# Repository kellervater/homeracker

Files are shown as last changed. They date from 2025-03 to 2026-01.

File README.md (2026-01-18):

[📚 What's it for?](#-use-cases) | [⚙️ How does it work?](#-features) | [🌐 Free & OpenSource](#-open-specs) | [🤝 Contributing](CONTRIBUTING.md)

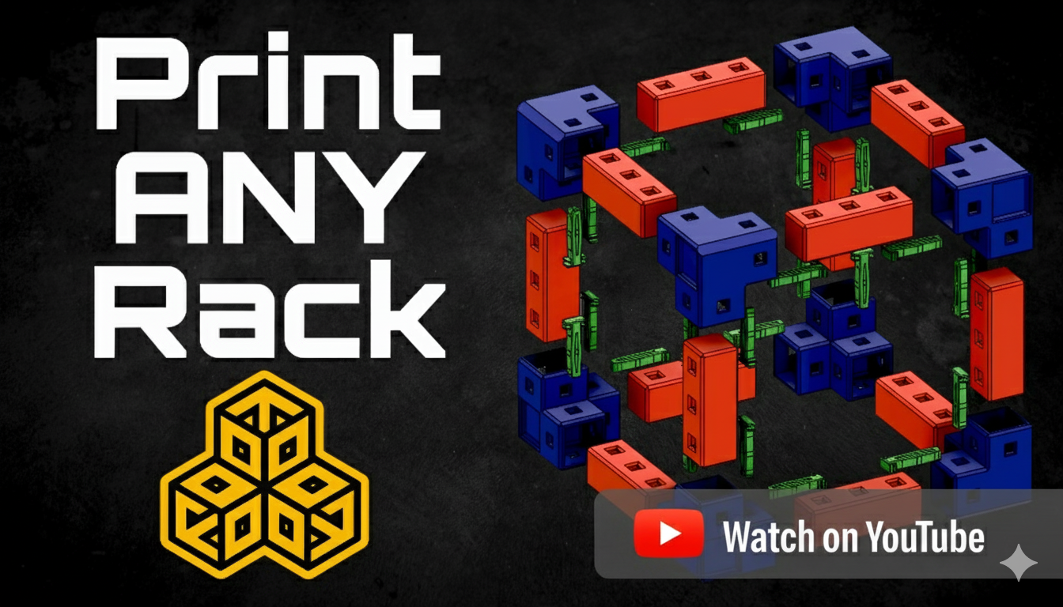
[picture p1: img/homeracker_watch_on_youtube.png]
What is HomeRacker - YouTube video (https://youtu.be/g8k6X_axYug)


HomeRacker is a fully modular 3D-printable rack-building system for virtually any “racking needs” (server rack, shoe rack, bookshelf, you name it).

You can find all parametric and non-parametric models, as well as the `.f3d` files (like the `HomeRacker - Core`), on [Makerworld](https://makerworld.com/en/@kellerlab).

The parametric models are available in the [HomeRacker GitHub Repository](https://github.com/kellerlabs/homeracker/tree/main/models).

> 💡 **Note**
> The basic HomeRacker system is also referred to as `HomeRacker - Core`. Free for everyone to use, remix, and reshare.

# 📑 Table of Contents
- [🔧 Use Cases](#-use-cases)
- [✨ Features](#-features)
  - [⚙️ How it works](#%EF%B8%8F-how-it-works)
    - [🛠️ Assembly Basics](#%EF%B8%8F-assembly-basics)
    - [💡 Assembly Tips](#-assembly-tips)
    - [🖨️ Printing Tips](#%EF%B8%8F-printing-tips)
- [📐 Tech Specs](#-tech-specs)
  - [🧱 Supports](#-supports)
  - [🔗 Connectors](#-connectors)
  - [📏 Lock Pins](#-lock-pins)
  - [🌍 Open Specs](#-open-specs)
- [💬 Community](#-community)
- [❓ Why the name?](#-why-the-name)
- [📜 Licensing](#-licensing)
- [🤝 Contributing](CONTRIBUTING.md)
- [🛠️ Developer Tools](#%EF%B8%8F-developer-tools)
- [🚀 Releases](#-releases)
- [🧪 Tests](#-tests)
  - [⚠️ Disclaimer](#%EF%B8%8F-disclaimer)
  - [🔬 How I tested](#-how-i-tested)

# 🔧 Use Cases
I created HomeRacker because I was dissatisfied with the existing solutions available online.
Many designs were too specific—accommodating only certain devices owned by their creators. Others supported only the 10" standard, with no flexibility for deviations, often requiring additional adapters.

As I began my homelab journey in April 2025, I wanted a modular solution that could adapt and grow with my evolving needs. This would eliminate the need to purchase larger racks or completely change concepts when the original design no longer met my requirements.

xkcd: The General Problem

As it is my nature to overengineer everything, I came up with a more generic solution to serve ANY racking need. Be it a small rack for a few Raspberry Pis, a 10" standard rack for homelabs, or even a 19" standard rack (still working on that though). You can even create bookshelves, shoe racks—or combine all of the above into an abomination of a rack.

To give you an idea of how this may look (10" rack, half-constructed Pi mini-rack, bookshelf):

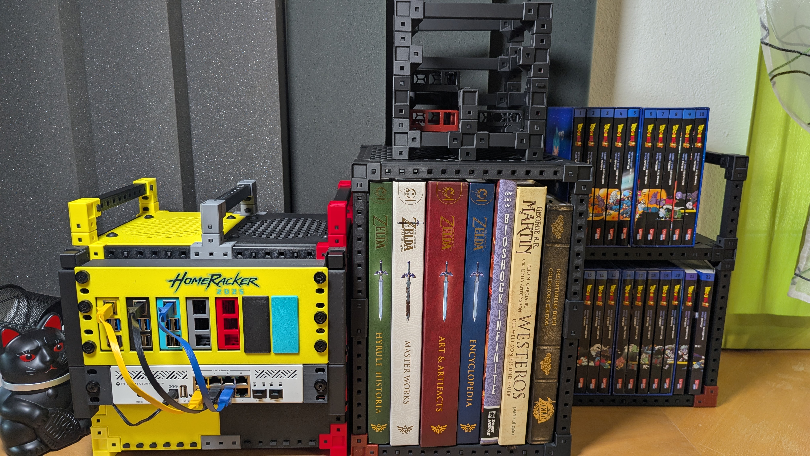
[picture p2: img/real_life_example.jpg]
Real Life Example


Aside from the basic [building blocks](#-tech-specs), the rack above also contains the following parts:

* **10" Rack**
  * [HomeRacker - 10" Rackmount Kit](https://makerworld.com/en/models/1353730-modular-10-server-rack#profileId-1396904) for standard-height units
  * [Raspi 5 Mount Kit](https://makerworld.com/en/models/1324096-pi-5-snapcase-for-homeracker#profileId-1360937):
    * Vertical Mount Adapter for HomeRacker
    * Front panel for 10" racks
  * Rackmount ears for the switch. These are fully customizable rackmount ears I created as an [OpenSCAD file](https://github.com/kellerlabs/homeracker/blob/main/models/rackmount_ears/rackmount_ears.scad). You can customize it directly [here](https://makerworld.com/en/models/1259227-fully-customizable-rackmount-ears#profileId-1283271).
  * [HomeRacker Airflow Kit](https://makerworld.com/en/models/1353730-modular-10-server-rack#profileId-1396904) (currently part of the 10" rack model), which consists of:
    * Front/back panels
    * Side panels
    * Bottom/top panels with air intake/exhaust grids and bores for standard fans (80/92/120mm)

* **Shelf** (Build any shelf configuration you like.)

# ✨ Features

The `HomeRacker - Core` features:

* **Fully modular** – Thanks to the support-connector system, you can scale in any direction. The only limits are material strength—and how much money, space, and time you have.
* **3D-printable** – The entire core system is printable, and no tools are required for assembly.
* **No supports needed** – Not a single part of the core system needs printed supports.
* **OpenSource** – Build your own adapters and use the system in personal or commercial projects (see [🌍 Open Specs](#-open-specs) and [📜 Licensing](#-licensing) for details).

## ⚙️ How it works
> **tl;dr** Think of a rack shape you want to build, download the model (insert link), print it, assemble it, and add your own mounts/adapters/whatever-you-like.

I might post a YouTube video here to show how it works.

### 🛠️ Assembly Basics

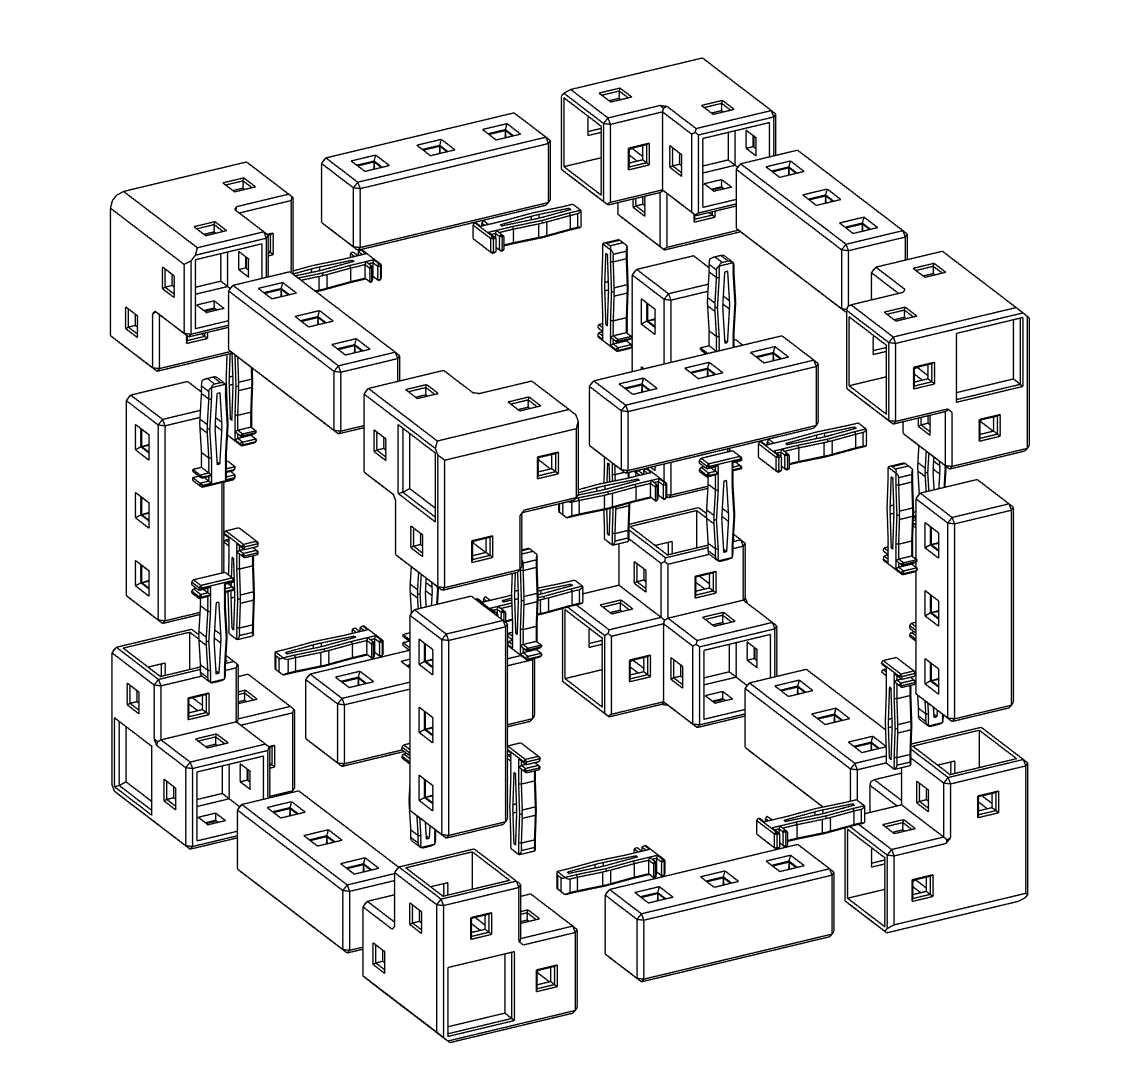
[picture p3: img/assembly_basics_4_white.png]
Assembly Basics 4 White


Assembly is straightforward and requires no tools:

1. **Prepare the components**: Download the HomeRacker - Core (❗Todo: insert link), and print all required parts. Clean off any debris.
2. **Connect supports and connectors**: Attach connectors to supports based on your desired configuration.
3. **Secure with Lock Pins**: Use Lock Pins to lock parts in place. They can be inserted horizontally or vertically thanks to their square profile.
4. **Add features**: Attach panels, shelves, and other accessories as needed.

### 💡 Assembly Tips

> 💡 **Pro Tip**: I created a sample 10" Cyberpunk-themed 3D model on MakerWorld (❗Todo: insert link) for inspiration.

1. Plan ahead! Otherwise, you'll end up with an army of unused parts like me:

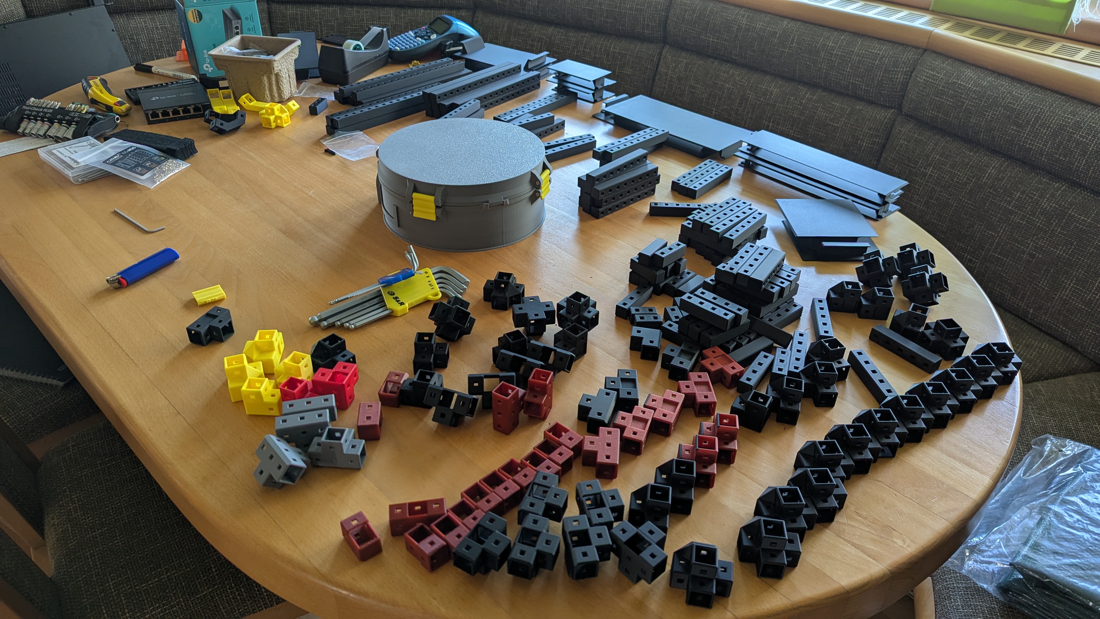
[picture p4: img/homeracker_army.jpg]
Army of Parts
   

   Make a parts list:
   * How many supports of what lengths (in `base units`)?
   * How many connectors of each type (pull-throughs, feet, regular)?
   * Print a ton of Lock Pins. You’ll need more than you might think. The model (❗Todo: insert link) on Makerworld should include a 100-pin plate and a [Gridfinity](https://gridfinity.xyz/) box for storage.

2. Build layer by layer: Start with the base frame, add vertical supports, then stack intermediate/top frames.
3. Make sure Lock Pins are fully inserted—gentle force might be needed.

### 🖨️ Printing Tips

1. If bed adhesion is sketchy: Add a brim to the supports. The small contact surface on connectors can cause print failures.
2. Prevent warping: Keep the print bed clean and oil-free. Even a fingerprint can cause issues.
3. When printing new filament: Make sure to calibrate the material flow!
> 💡 **Pro Tip**: If you need to disassemble and the pin is stuck, push it from the other side with another pin to release it.

## 📐 Tech Specs

> 💡 **Note** - For actual dimensions, check out the original Fusion `.f3d` files on Makerworld. All designs are fully parameterized for easy scaling.

The system is based on 4 core measurements:

1. **15mm** – The `base_unit`. Each support has 15mm x/y dimensions, with z being a multiple of 15mm.
2. **4mm** – Side length of Lock Pins and matching holes.
3. **2mm** – Wall thickness of connectors.
4. **0.2mm** – Tolerance added to connector interiors for print/material variances.

> These values (except tolerance) are arbitrary—just made sense during design.

### 🧱 Supports

Supports are the structural spine of HomeRacker.

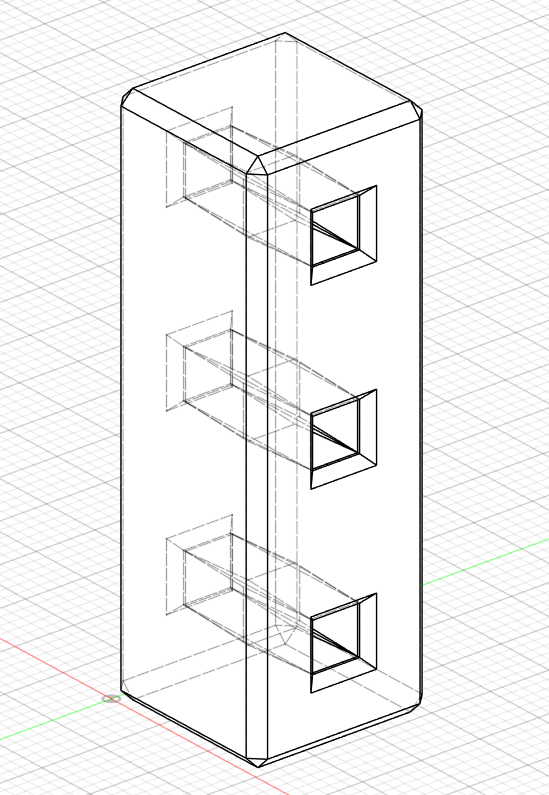
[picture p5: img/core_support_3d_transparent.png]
Core Support 3D Transparent


Height is a multiple of 15mm (base units).
E.g.: A 3-unit support = 45mm tall, a 17-unit = 255mm.

Each unit height includes a 4mm hole for a Lock Pin.

* Holes match Lock Pin dimensions (no tolerance).
* Holes are convex on x and z axes for multi-directional insertion.

Schematics:

**Front View**
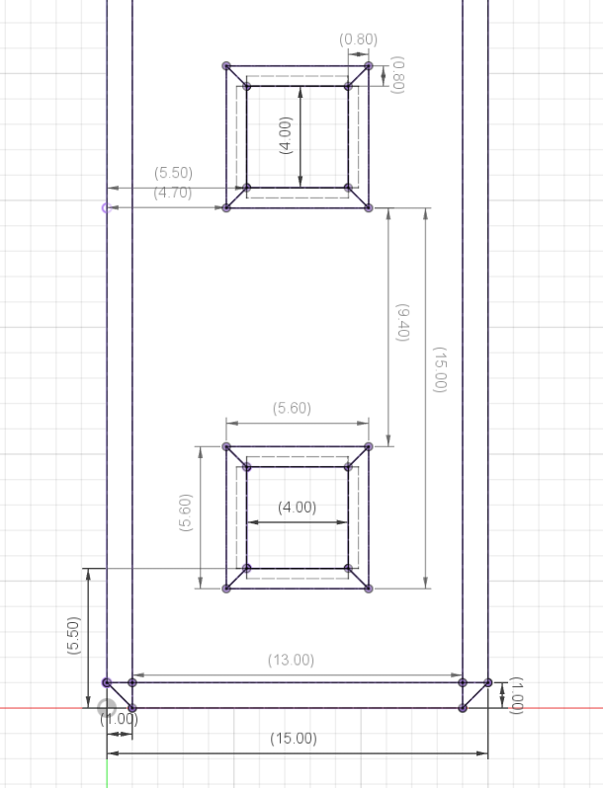
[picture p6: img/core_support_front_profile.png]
Support Front View


**Side View**
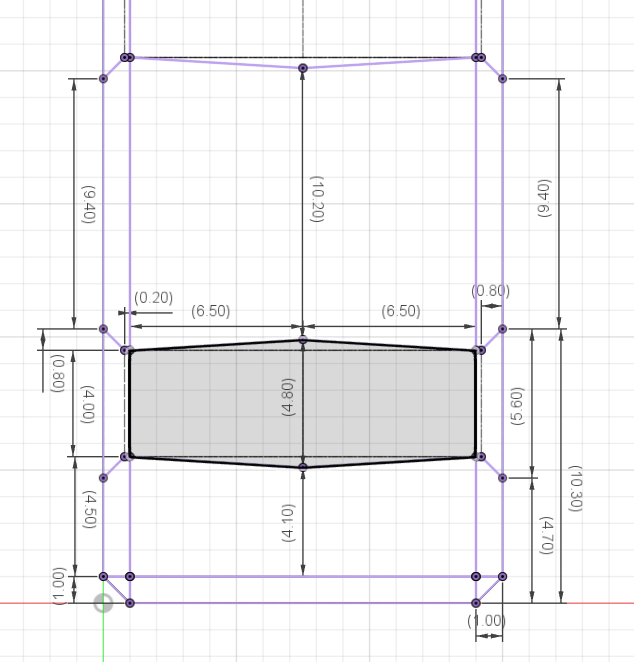
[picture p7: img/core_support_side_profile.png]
Support Side View


**Top View**
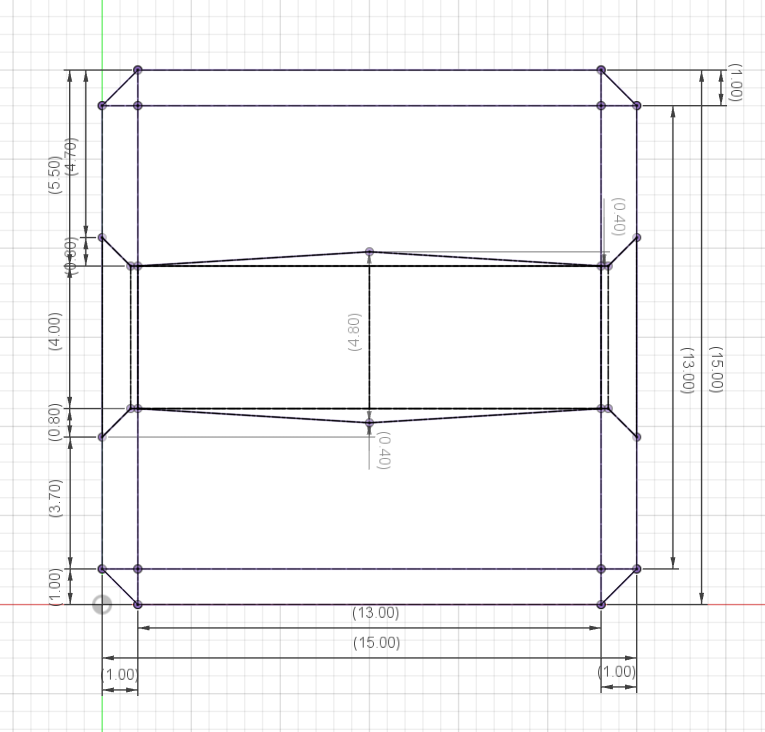
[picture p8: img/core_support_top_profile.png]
Support Top View


### 🔗 Connectors

Connectors join supports in 1 to 3 dimensions.
From straight extenders to 6-way junctions.

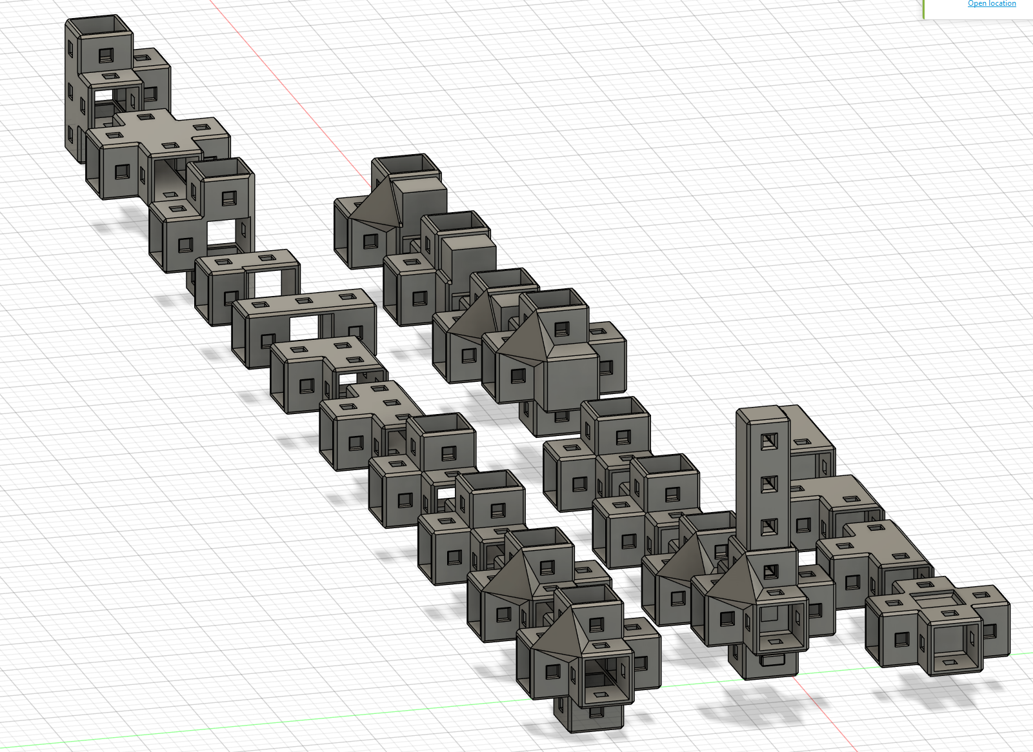
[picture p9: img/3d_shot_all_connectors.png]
3D Shot of All Connectors


Types:
* **Standard** – Solid center; best for load-bearing.
* **Pull-Through** – Open center for complex builds (e.g. 10" rack).
* **Feet** – Solid end pieces; used as rack feet.

> ❗ **Important**
> Connector centers are always 1 `base_unit` in height. No offsets, no fluff.
> So: 2 × 3-unit supports + 1 connector = exactly 7 base units (105mm).

Schematics:

**Top View – Outer**
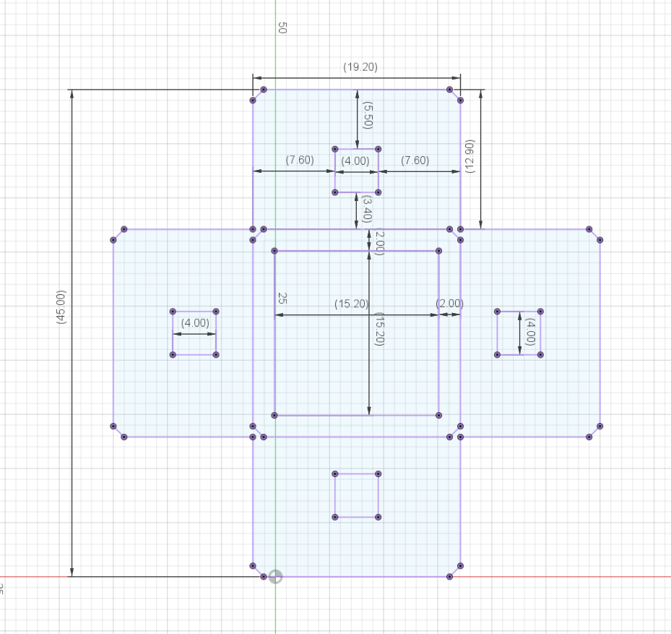
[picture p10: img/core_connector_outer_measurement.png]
Connector Outer Measurements


**Top View – Inner**
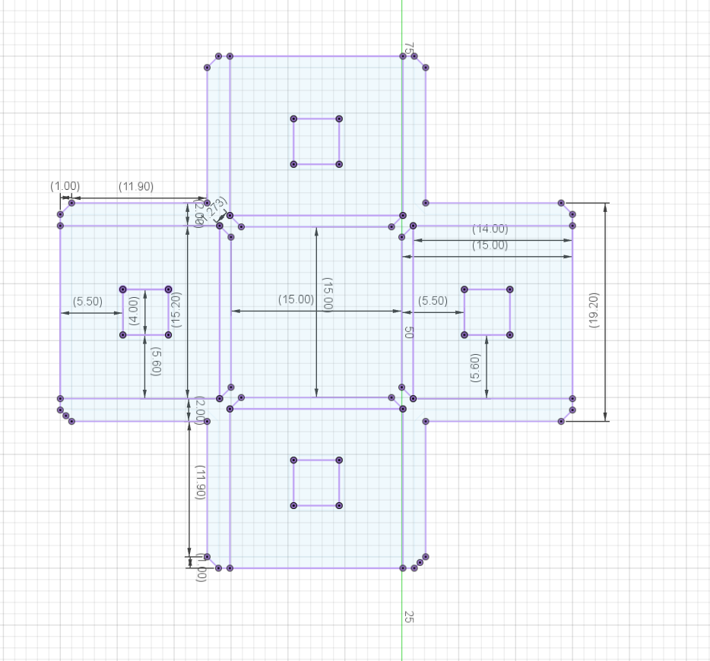
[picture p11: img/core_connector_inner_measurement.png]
Connector Inner Measurements


### 📏 lock Pins

Lock Pins hold the system together.

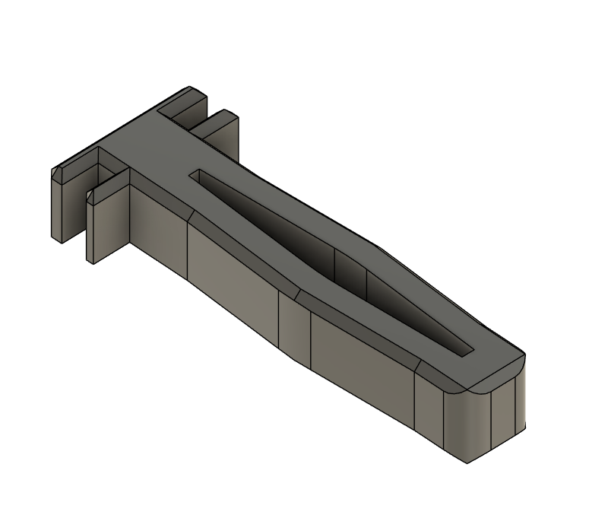
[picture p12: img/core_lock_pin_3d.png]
lock Pin 3D


They rely on tension from their convex shape to stay in place.

Schematics:

**Top View**
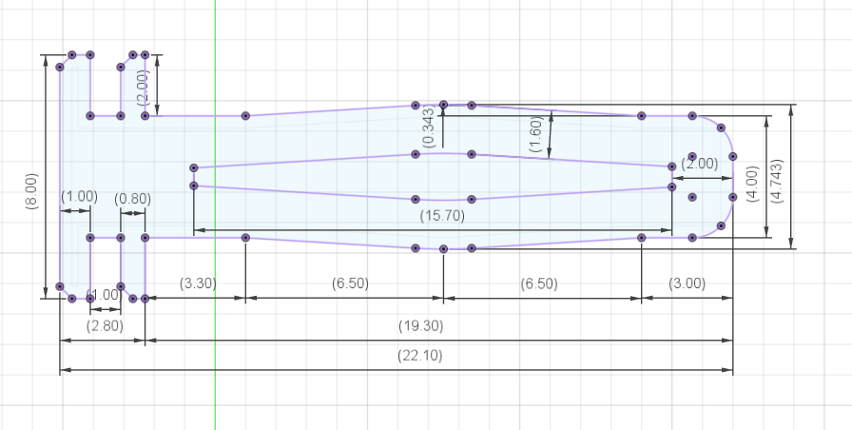
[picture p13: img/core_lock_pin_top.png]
lock Pin Top


**Side View**
> Don’t ask why the height is 3.791mm—it works. I left it as-is.

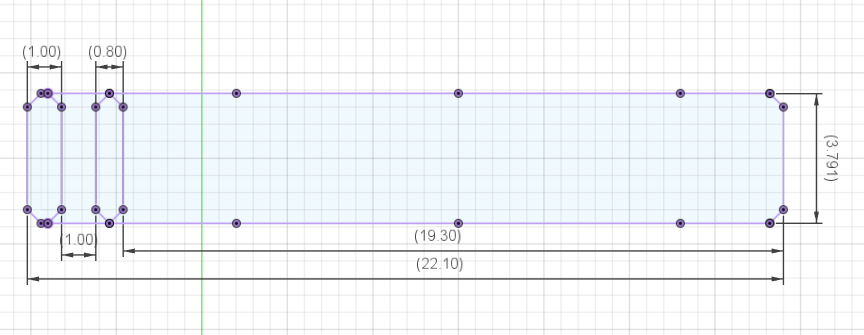
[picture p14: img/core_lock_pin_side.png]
lock Pin Side


> I may tweak the pin grip in future versions for to make it easier to pull-out again. But the base dimensions will remain the same for compatibility.

## 🌍 Open Specs

I created `HomeRacker - Core` to be an open spec that any maker can build on, with (almost) no strings attached.
(See [📜 Licensing](#-licensing) for more.)

I encourage you to make your own models based on HomeRacker!
Let me know, and I’ll feature your work on this page and cross-link it on Makerworld (subject to my "very objective" approval 😄).
Just [create an issue](https://github.com/kellerlabs/homeracker/issues/new) if you want to be featured.

# 💬 Community

Got questions? Want to share your builds? Join the HomeRacker community!

- **💬 [Discord](https://discord.gg/b6myzHRxc3)** – Chat with me and other builders, get help, share ideas
- **🎥 [YouTube](https://www.youtube.com/@kellerlabs)** – Watch build guides, tutorials, and project updates
- **🖨️ [Makerworld](https://makerworld.com/@kellerlab)** – Grab ready-to-print models and remixes

Whether you're just starting out or have a wild idea for a custom rack, I'd love to hear from you. The HomeRacker community is all about sharing knowledge and helping each other build cool stuff!

# ❓ Why the name?

After ~4 hours of research, I found all my original ideas (UniRack, OpenRack, etc.) were taken.

So, "HomeRacker" was born—part practical, part tongue-in-cheek. It fits the homelab theme, but also hints at the "home-wrecking" time sink this can become.

# 📜 Licensing

> 💡 **tl;dr**
>  – Use it for ANY purpose (even commercial), but credit me and share alike!

* Source code: `MIT License` ([LICENSE](https://github.com/kellerlabs/homeracker/blob/main/LICENSE))
* 3D models & creative assets (`/models/`): `CC BY-SA 4.0 License` ([/models/LICENSE](https://github.com/kellerlabs/homeracker/blob/main/models/LICENSE))

These licenses apply to the `HomeRacker - Core` system and customizable rackmount ears.

> ❗ **Important**
> Other models I publish may have more restrictive licenses. This will be stated clearly on Makerworld.

HomeRacker is an unregistered trademark of Patrick Pötz (), first used publicly on 12.04.2025.

# 🛠️ Developer Tools

HomeRacker includes custom tooling to streamline development:

- **[scadm](cmd/scadm/README.md)** - OpenSCAD + library dependency manager
  - Zero-dependency Python package for installing OpenSCAD (nightly/stable) and libraries
  - Cross-platform: Windows, Linux, macOS (might work, dunno)
  - Install: `pip install scadm` → `scadm`
  - Manages dependencies from `scadm.json`

- **[Renovate Preset](renovate-dependencies.json)** - Automated dependency updates
  - Tracks OpenSCAD versions, GitHub releases, and Python packages
  - Custom rules for this project's specific needs
  - Extend in your project: `"extends": ["github>kellerlabs/homeracker:renovate-dependencies"]`

See [CONTRIBUTING.md](CONTRIBUTING.md) for setup instructions.

# 🚀 Releases

HomeRacker uses automated releases powered by Camunda's GitHub actions:

- **Automated versioning**: Follows [Semantic Versioning](https://semver.org/) based on [Conventional Commits](https://www.conventionalcommits.org/)
- **Changelog generation**: Automatically generated from commit messages
- **Release schedule**: Weekly auto-merge of release PRs (or manual trigger)
- **GitHub releases**: Tagged releases with changelog and version information
- **PR validation**: Pull request titles are validated to ensure Conventional Commits compliance

The release automation uses [Camunda's infra-global-github-actions](https://github.com/camunda/infra-global-github-actions/tree/main/teams/infra/pull-request) for release management and auto-merging.

To contribute and trigger releases, use conventional commit messages. See [CONTRIBUTING.md](CONTRIBUTING.md#-commit-conventions) for details.

# 🧪 Tests

Of course I tested stuff... It took ~4 months from idea to this release.
Look at all the prototypes:
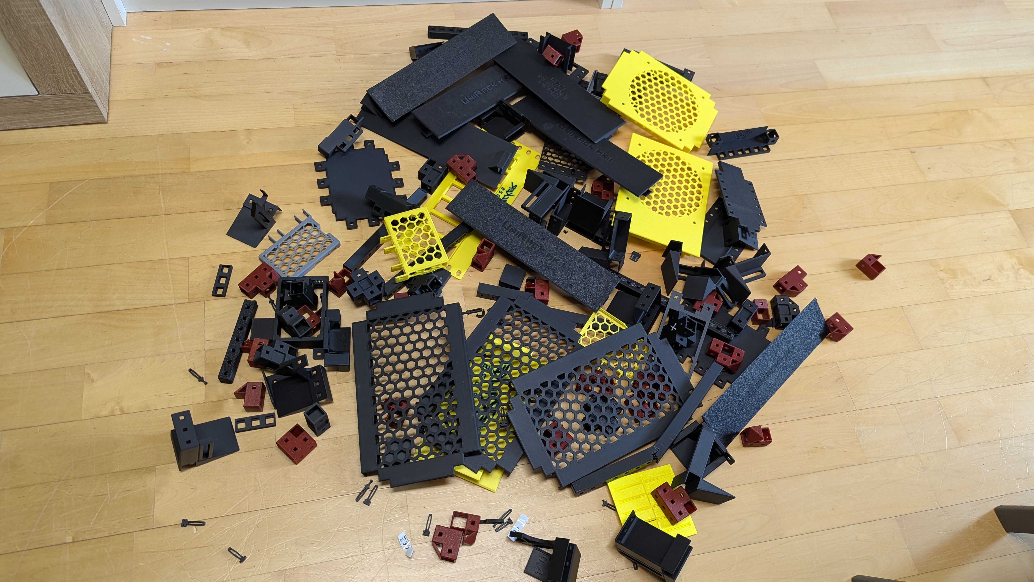
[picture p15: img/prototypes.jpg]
Photo showing a variety of HomeRacker prototypes lined up


## ⚠️ Disclaimer

> ⚠️ **Warning**
> This project is provided “as is,” without any warranty. Use at your own risk. I’m not responsible for damage, injury, or loss caused by using this system or its parts.

Aside from the scary warning above, I need to mention, that due to the high modularity of this system combined with limited time and resources I was of course not able to test every combination of filaments, printers, print-settings, room conditions (temperature, humidity) or to do extensive load-bearing tests.

What I want to say:
I feel like the model turned out to be really nice and versatile. That's why I shared it in the first place.
But since I do not have control over the manufacturing conditions of any consumer of this model, I cannot give any guarantees on how your specific print will turn out in the end. There are just too much variables which not even the best model design can compensate for. (Writing this feels a bit like an upfront apology... seems like I'm a people pleaser)

## 🔬 How I tested
My setup is as follows:
* a room temperature between 17 and 25°C
* Humidity levels between 29% and 36% (depends on when I'm doing my laundry)
* A BambuLab X1C printer
* Exclusively BambuLab filament (haven't tried others yet)
  * PLA Matte (I love the charcoal color. Looks so silky)
  * PLA Basic
  * ABS
* mostly I used the Textured PEI plate. It just works (provided you regularly clean it using Isopropyl alcohol). For the rest of the time I tried out the Cold Plate Super Track (it's nice but very hard to get your prints of the plates when it cools)

All above's filament types can be be combined in any possible way (just make sure you do flow calibration before using new filaments. First ABS print turned out horribly just because I forgot to click the calibration checkbox).
E.g.: you could print a connector in ABS, a support in PLA Matte and a Lock Pin in PLA and they will just fit when being assembled.

> 🛠️ **Btw:** I am not affiliated with Bambu in any way besides uploading my models to MakerWorld and occasionally making use of their Exclusive Model program. But they don't pay me for naming their products anywhere else (I wish 😉).

# Logo
This logo will also be used as an overlay image for the thumbnails of all my 3D models that are compatible with HomeRacker.
I encourage you to do the same if you create models for HomeRacker. That way, it’ll be immediately visible to users that a model is designed to be mounted on a HomeRacker system.
I also svg'ed this logo [here](img/homeracker_logo.svg) and [here](img/homeracker_logo_single_color.svg).

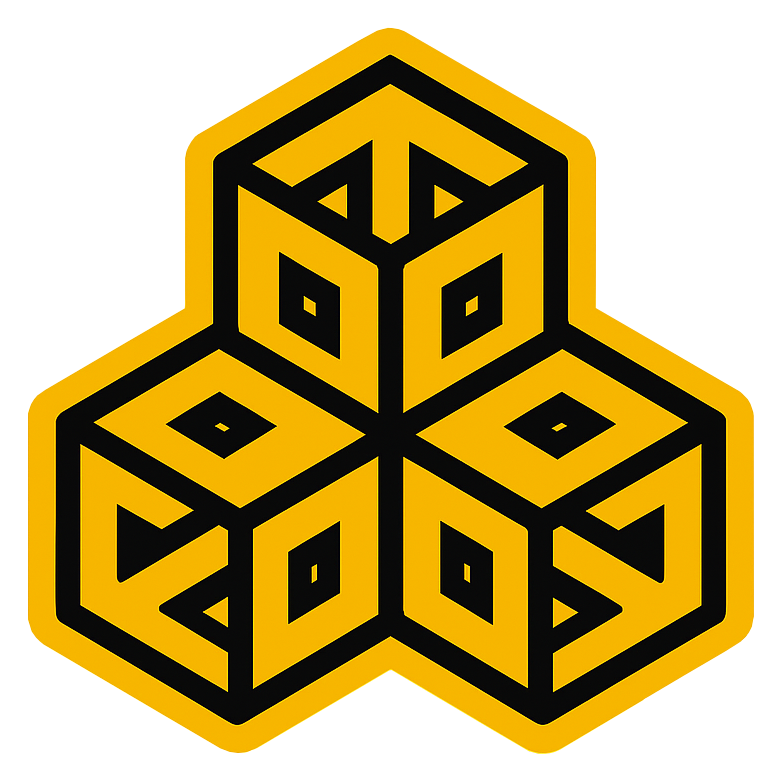
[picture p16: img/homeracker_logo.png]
HomeRacker Logo


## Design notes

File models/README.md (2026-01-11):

# Models
This folder contains all `scad` 3d models which come with the HomeRacker project.

## Contents

### Core
The fundamental HomeRacker building system with modular components:
- **Supports**: Vertical and horizontal structural elements
- **Connectors**: Join supports in a variety of dimensions
- **Lock Pins**: Secure connections without tools

See [core/README.md](core/README.md) for details.

### Gridfinity
Gridfinity-compatible components for modular storage integration:
- **Baseplates**: Mounting surfaces for Gridfinity bins (42mm grid)
- **Bin Bases**: Foundation for custom Gridfinity-compatible containers
- Spec-compliant with [grizzie17's Gridfinity specification](https://www.printables.com/model/417152-gridfinity-specification)

See [gridfinity/README.md](gridfinity/README.md) for details.

### Rackmount Ears
Fully customizable rackmount ears for standard rack mounting.

Examples:
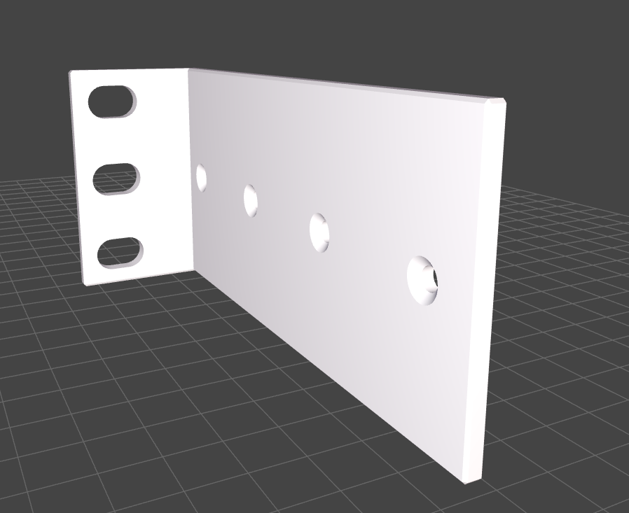
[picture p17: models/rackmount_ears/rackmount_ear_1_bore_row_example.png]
Only 1 Bore Row

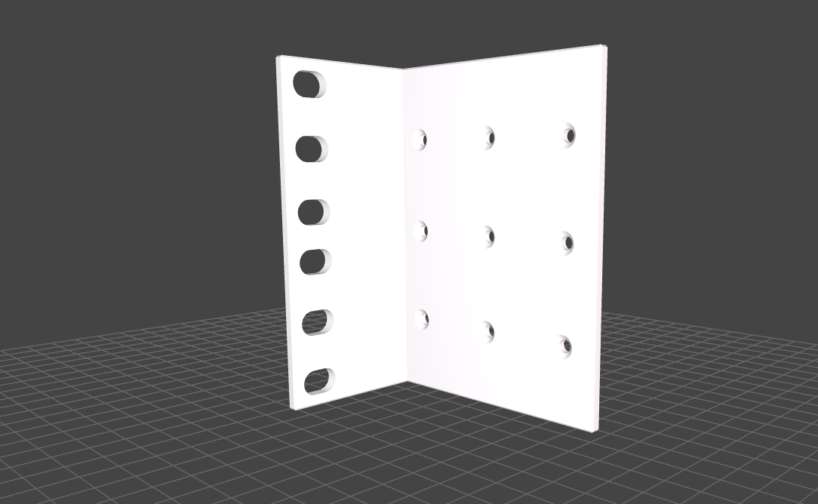
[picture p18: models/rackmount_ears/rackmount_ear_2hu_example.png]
2 Height Units


---

**MakerWorld exports**: Files in `<model_type>/parts/` are automatically exported on commit. See [cmd/export/README.md](../cmd/export/README.md) for details.

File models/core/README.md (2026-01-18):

# HomeRacker Core

The core building system for HomeRacker - the fully modular 3D-printable rack-building platform.

## 📁 Structure

```
core/
├── main.scad          # Main library entry point - include this to use base HomeRacker modules from `lib`
├── lib/               # Core module definitions (implementation)
│   ├── connector.scad  # Connector module implementation
│   ├── support.scad    # Support beam module implementation
│   ├── lockpin.scad    # Lock pin module implementation
│   └── constants.scad  # Shared constants and dimensions
├── parts/              # Single customizable instances of `lib` modules
│   ├── connector.scad  # Fully customizable connector (use OpenSCAD Customizer)
│   ├── support.scad    # Fully customizable support beam
│   └── lockpin.scad    # Fully customizable lock pin
└── presets/            # Pre-configured variant collections
    ├── connectors.scad # All useful connector variants for export
    ├── supports.scad   # All useful support variants for export
    └── lockpins.scad   # All useful lock pin variants for export
```

## 🚀 Quick Start

### Using the Library

Include the core library in your OpenSCAD projects:

```scad
use <core/main.scad>

// Create a 3-directional connector
connector(dimensions=3, directions=3);

// Create a support beam (3 units long)
support(units=3);

// Create a lock pin with standard grip
lockpin(grip_type="standard");
```

### Customizing Parts

Open any file in `parts/` with OpenSCAD and use the **Customizer** panel to adjust parameters:

- **`connector.scad`**: Customize dimensions, directions, pull-through axes, feet, and orientation
- **`support.scad`**: Customize length and hole configurations
- **`lockpin.scad`**: Customize grip type (standard, extended or no-grip)

### Exporting Variants

The `presets/` folder contains modules for batch-exporting all logical variants:

- **`connectors.scad`**: Organized collections (standard, feet, pull-through, etc.)
- **`supports.scad`**: Various support lengths with different hole configurations
- **`lockpins.scad`**: Standard grip, extended and no-grip variants

## 🔧 Core Components

### 1. **Supports** (Beams)
Structural elements with standardized connection points.
- 15mm × 15mm cross-section
- Configurable length (multiples of 15mm)
- Optional X-axis holes for cable management

### 2. **Connectors**
Junction pieces that join supports in multiple directions.
- 1D, 2D, or 3D variants (up to 6 directions)
- Optional feet for vertical stability
- Optional pull-through axes for complex builds
- Lock pin holes (4mm square pins)

### 3. **Lock Pins**
4mm square pins that secure connectors to supports via tension fit.
- Standard grip: Two grip arms for easy insertion/removal
- Extended grip: Two asymmetric grip arms with a dominant outer arm.
- No-grip variant: Smooth design for minimal profile
- Bidirectional tension hole for secure fit

## 📐 Dimensional Standards

- **Base Unit**: 15mm
- **Lock Pin**: 4mm square
- **Wall Thickness**: 2mm
- **Tolerance**: 0.2mm (built into connectors)
- **Standard Chamfer**: 1mm
- **Lock Pin Chamfer**: 0.8mm

## 📝 License

- **Source Code**: MIT License
- **3D Models**: CC BY-SA 4.0

## 🔗 Resources

- [Main Repository](https://github.com/kellerlabs/homeracker)
- [BOSL2 Library Documentation](https://github.com/BelfrySCAD/BOSL2/wiki)

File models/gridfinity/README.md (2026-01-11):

# HomeRacker Gridfinity

Gridfinity-compatible baseplates and bin bases implemented as reusable OpenSCAD modules for anyone to use.
This library is intended to make it easier to integrate Gridfinity interfaces to your models.

If you want to create a Gridfinity compatible shelf or drawer, use the `baseplate` module.
If you want to create a custom Gridfinity bin, use the `binbase` module.

## 📁 Structure

```
gridfinity/
├── base.scad           # Legacy entry point (deprecated - use lib/ modules)
├── lib/                # Gridfinity module definitions (implementation)
│   ├── baseplate.scad  # Baseplate module implementation (for surfaces)
│   └── binbase.scad    # Bin base module implementation (for containers)
├── parts/              # Single customizable instances of `lib` modules
│   ├── baseplate.scad  # Fully customizable baseplate (use OpenSCAD Customizer)
│   └── binbase.scad    # Fully customizable bin base
└── makerworld/         # Export-ready variants for MakerWorld
    ├── baseplate.scad  # Pre-configured baseplate variants
    └── binbase.scad    # Pre-configured bin base variants
```

## 🚀 Quick Start

### Using the Library

Include Gridfinity modules in your OpenSCAD projects:

```scad
include <gridfinity/lib/baseplate.scad>
include <gridfinity/lib/binbase.scad>

// Create a 3×2 baseplate
baseplate(units_x=3, units_y=2);

// Create a 1×2 bin base
binbase(units_x=3, units_y=2);

// This is a nice example as it places the binbase exactly onto the baseplate.
// Lets you examine tolerances :-D
```

### Customizing Parts

Open any file in `parts/` with OpenSCAD and use the **Customizer** panel to adjust parameters:

- **`baseplate.scad`**: Customize grid dimensions (x and y units)
- **`binbase.scad`**: Customize grid dimensions and preview with baseplate

### Exporting Variants

The `makerworld/` folder contains pre-configured variants for export as self-contained files to MakerWorld or other platforms.

## 🔧 Core Components

### 1. **Baseplate**
Mounting surface for Gridfinity bins and organizers.
- Standard Gridfinity 42mm grid spacing
- Precise dimensional compliance with grizzie17's specification
- Optimized for 0.4mm nozzle printing
- Compatible with all standard Gridfinity bins

### 2. **Bin Base**
Bottom mounting component for custom Gridfinity-compatible containers.
- Standard Gridfinity 42mm grid spacing
- Matches baseplate cutout geometry
- Stack securely on Gridfinity baseplates
- Build custom bins on top of this foundation

## 📐 Dimensional Standards

All dimensions follow [grizzie17's Gridfinity specification](https://www.printables.com/model/417152-gridfinity-specification) for maximum compatibility.

## 📝 License

- **Source Code**: MIT License

## 🔗 Resources

- [BOSL2 Library Documentation](https://github.com/BelfrySCAD/BOSL2/wiki)
- [Gridfinity Specification](https://www.printables.com/model/417152-gridfinity-specification)

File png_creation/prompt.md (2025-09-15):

# --- Gemini Agent Prompt: Create Tool Silhouette ---

**ROLE:**
You are an expert image processing agent. Your sole function is to create a clean, solid black silhouette from a user-provided image of a tool.

**TASK:**
Analyze the attached image and generate a PNG file that meets the precise output requirements below. This PNG will be used as a source for a vector tracing program (Potrace), so precision is critical.

**INPUT:**
- An image file of a single tool lying on a high-contrast background.

**OUTPUT REQUIREMENTS:**
1.  **Format:** PNG with a transparent background.
2.  **Content:** A silhouette representing the **single, continuous, outermost contour only**. All internal holes, lines, and details must be completely filled in.
3.  **Color:** The silhouette must be 100% solid black (`#000000`). No anti-aliasing or grey pixels.
4.  **Cropping:** The final image must be tightly cropped around the silhouette with minimal transparent padding.

**ACTION:**
Process the attached photo and provide only the resulting PNG file as your output.

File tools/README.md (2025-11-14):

# 🔧 OpenSCAD Installation Scripts

Automated installation of OpenSCAD for the HomeRacker workspace (Windows only atm).

## 📦 Quick Start

```bash
# Install or upgrade to latest nightly release (default)
./tools/install-openscad.sh

# Install nightly build (default)
./tools/install-openscad.sh --nightly

# Install dependencies (BOSL2 library) - already done on a fresh install-openscad call
./tools/install-dependencies.sh

# Check if update is available
./tools/install-openscad.sh --check

# Run smoke test - validates the current openscad installation against local models
./tools/install-openscad.sh --test

# Force reinstall
./tools/install-openscad.sh --force
```

## 🤖 Automatic Updates

Versions are tracked in the scripts and managed by Renovate Bot. When new releases are available, Renovate creates a PR to update the versions. After merging, run the install scripts to upgrade.

## 📝 Notes

- **Default**: Nightly snapshots - latest features and fixes
- **Stable**: Release 2021.01 - use `--stable` flag for BOSL2 compatibility
- **Current support**: Windows only (via Git Bash)
- **Future**: macOS/Linux support tracked in [#40](https://github.com/kellervater/homeracker/issues/40)
- **BOSL2**: Installed to bundled libraries directory
- **Source**: https://files.openscad.org/

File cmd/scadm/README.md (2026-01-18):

# scadm - OpenSCAD Dependency Manager

**scadm** is a lightweight, python-based dependency manager for OpenSCAD projects. It simplifies installing OpenSCAD (nightly or stable) and managing library dependencies through a simple `scadm.json` file.

## Features

- 🚀 **Install OpenSCAD**: Automatically downloads and installs OpenSCAD (nightly or stable builds)
- 📦 **Manage Libraries**: Install OpenSCAD libraries (BOSL2, MCAD, custom libraries) from GitHub
- 🔄 **Version Tracking**: Keeps dependencies in sync with your project
- 📋 **Simple Config**: Define dependencies in a single `scadm.json` file

## Installation

**Requirements:** Python 3.11 or newer

```bash
pip install scadm
```

## Quick Start

### 1. Create `scadm.json` in your project root

```json
{
  "dependencies": [
    {
      "name": "BOSL2",
      "repository": "BelfrySCAD/BOSL2",
      "version": "266792b2a4bbf7514e73225dfadb92da95f2afe1",
      "source": "github"
    }
  ]
}
```

### 2. Install OpenSCAD and dependencies

```bash
scadm install
```

This will:
- Download and install OpenSCAD to `bin/openscad/`
- Install all libraries defined in `scadm.json` to `bin/openscad/libraries/`

## Usage

### Check version

```bash
scadm --version
```

### Install everything (OpenSCAD + libraries)

```bash
scadm install                # Install nightly build (default - RECOMMENDED)
scadm install --stable       # Install stable release (2021.01)
```

> [!NOTE]
> Nightly builds are installed by default since the stable release (2021.01) is outdated and missing modern features. All nightly versions pass rendering tests before being published to ensure quality.

### Check installation status

```bash
scadm install --check
```

### Force reinstall

```bash
scadm install --force
```

### Install only OpenSCAD

```bash
scadm install --openscad-only
```

### Install only libraries

```bash
scadm install --libs-only
```

### Configure VS Code extensions

These are opinionated QoL improvements to install nifty VSCode extensions which improve DevEx.

```bash
scadm vscode --openscad   # Install and configure OpenSCAD extension
scadm vscode --python     # Install and configure Python extension
```

**OpenSCAD extension** will:
- Install the `Leathong.openscad-language-support` extension
- Configure VS Code settings with correct OpenSCAD paths
- Merge with existing settings (preserves unrelated configurations)

**Python extension** will:
- Install the `ms-python.python` extension
- Configure default interpreter path to `${workspaceFolder}/.venv` (eliminates need to manually source venv when opening project)

> [!NOTE]
> Settings are opinionated defaults designed to streamline development experience. They're configured in `.vscode/settings.json` (workspace-level), not globally.

> [!IMPORTANT]
> Requires VS Code CLI (`code` command) to be available in PATH. If not found, you'll receive installation instructions.

## Configuration

### `scadm.json` Schema

```json
{
  "dependencies": [
    {
      "name": "BOSL2",
      "repository": "BelfrySCAD/BOSL2",
      "version": "266792b2a4bbf7514e73225dfadb92da95f2afe1",
      "source": "github"
    },
    {
      "name": "homeracker",
      "repository": "kellerlabs/homeracker",
      "version": "v1.2.3",
      "source": "github"
    }
  ]
}
```

**Fields:**
- `name`: Library name (creates `bin/openscad/libraries/{name}/`)
- `repository`: GitHub repository in `owner/repo` format
- `version`: Git tag, commit SHA, or branch name
- `source`: Currently only `"github"` is supported

## Directory Structure

After running `scadm`, your project will have:

```
your-project/
├── scadm.json
├── models/
│   └── your_model.scad
└── bin/openscad/
    ├── openscad.exe (or openscad appimage)
    └── libraries/
        ├── BOSL2/
        └── homeracker/
```

## Use in OpenSCAD Files

```openscad
include <BOSL2/std.scad>
include <homeracker/core/lib/connector.scad>

// Your code here
```

## Renovate Integration

Keep your `scadm.json` dependencies automatically updated with [Renovate](https://docs.renovatebot.com/):

Add this preset to your `renovate.json`:

```json
{
  "extends": [
    "github>kellerlabs/homeracker:renovate-dependencies"
  ]
}
```

This preset enables automatic updates for:
- Git commit SHAs (for tracking main/master branches)
- Semantic version tags (v1.2.3)

## License

MIT

## Contributing

Issues and pull requests are welcome at [kellerlabs/homeracker](https://github.com/kellerlabs/homeracker).

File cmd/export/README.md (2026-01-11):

# MakerWorld Export Tool

Exports OpenSCAD models for MakerWorld's parametric feature by inlining all local includes into a single file.

## Usage

```bash
python cmd/export/export_makerworld.py <input.scad>
```

Output is written to `models/<model_type>/makerworld/<filename>.scad` where `<model_type>` is auto-detected from the input path (e.g., `core`, `gridfinity`).

## File Structure Assumptions

This script is opinionated about file structure, following **OpenSCAD Customizer** conventions:

**Root files** (files being exported, e.g., `parts/*.scad`):
1. Parameter sections: `/* [SectionName] */` with customizable variables
2. Hidden section: `/* [Hidden] */` with constants/variables hidden from UI
3. Main code: module/function calls that generate geometry

**Variable placement behavior:**
- Variables between `/* [Hidden] */` and first module/function → included in Hidden section (hidden from UI)
- Variables after main code (after last module call) → filtered out (not included in export)
- Best practice: Keep all non-parameter variables in `/* [Hidden] */` section before the first module call

**Library files** (included via `include <...>`):
- Must contain ONLY module/function definitions and constants
- Must NOT have parameter section markers (`/* [Name] */`)
- The script validates this and fails with an error if violated

> [!NOTE]
> Library files (included via `include <...>`) **must not** contain parameter section markers like `/* [Parameters] */` or `/* [Hidden] */`. Only the root file being exported should have these markers. The script will fail with a clear error if it detects parameter sections in library files.

## What it does

- Preserves BOSL2 library references (required by MakerWorld)
- Keeps parameter sections with their comments (for MakerWorld customizer)
- Inlines all local includes recursively
- Strips comments from inlined library code
- Prevents duplicate includes

## Example

```bash
python cmd/export/export_makerworld.py models/core/parts/connector.scad
# → models/core/makerworld/connector.scad

python cmd/export/export_makerworld.py models/gridfinity/parts/baseplate.scad
# → models/gridfinity/makerworld/baseplate.scad
```

## Testing

Use the automated export system:

```bash
# Export all configured models and validate
./cmd/export/export-core-models.sh
```

Or test a single model:

```bash
python cmd/export/export_makerworld.py models/core/parts/connector.scad
# → models/core/makerworld/connector.scad

python cmd/export/export_makerworld.py models/gridfinity/parts/baseplate.scad
# → models/gridfinity/makerworld/baseplate.scad
```

## Automated Export System

### Setup Pre-commit Hooks

This project uses the [pre-commit](https://pre-commit.com/) framework:

```bash
# Install pre-commit (if not already installed)
pip install pre-commit

# Install git hooks
pre-commit install
```

### Components

**`export-core-models.sh`** - Orchestrates the export process:
- **Auto-discovers** all `.scad` files from configured paths (`models/core/parts`, `models/gridfinity/parts`)
- Exports each via `export_makerworld.py` (auto-detects model type from path)
- Validates exports with `test-models.sh`

**Pre-commit hook** - Configured in `.pre-commit-config.yaml`:
- Runs `export-core-models.sh` **automatically on every commit**
- Validates exports are in sync with source files
- Only runs when model files in `models/**/*.scad` change
- **You don't need to manually export** - just commit and the hook does it for you

**Model type detection**:
- Input: `models/<model_type>/parts/file.scad` → Output: `models/<model_type>/makerworld/file.scad`
- Works for any model type (core, gridfinity, or future additions)
- Just add your `.scad` files to `<model_type>/parts/` and they'll be auto-exported

**GitHub Actions** - CI workflow runs all pre-commit hooks on PRs

### Running Manually

```bash
# Run all pre-commit hooks
pre-commit run --all-files

# Run only the MakerWorld export validation
pre-commit run validate-makerworld-exports --all-files
```

### Adding New Model Types

To add a new model type (e.g., `models/newtype/`):

1. Create your model files in `models/newtype/parts/*.scad`
2. Edit `cmd/export/export-core-models.sh` and add to `EXPORT_PATHS`:
   ```bash
   EXPORT_PATHS=(
       "models/core/parts"           # Folder: auto-discovers .scad files
       "models/gridfinity/parts"     # Folder: auto-discovers .scad files
       "models/newtype/parts"        # Your new model type
       # "models/newtype/special.scad" # Or: specific file only
   )
   ```
3. Commit - the pre-commit hook will automatically export to `models/newtype/makerworld/`

No other configuration needed - the export script auto-detects model types from paths.

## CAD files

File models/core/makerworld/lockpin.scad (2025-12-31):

include <BOSL2/std.scad>

/* [Parameters] */

// Type of grip for the lock pin
grip_type = "standard"; // ["standard","no_grip"]

// --- Examples ---

// Example 1: Create a default lock pin (uses default grip_type)
// lockpin();

// Example 2: Create a lock pin with no grip
// lockpin(grip_type="no_grip");

// Example 3: Create a lock pin with grip_type as set above
color(HR_YELLOW)
lockpin(grip_type=grip_type);

/* [Hidden] */
TOLERANCE = 0.2;
PRINTING_LAYER_WIDTH = 0.4;
PRINTING_LAYER_HEIGHT = 0.2;
BASE_UNIT = 15;
BASE_STRENGTH = 2;
BASE_CHAMFER = 1;
LOCKPIN_HOLE_CHAMFER = 0.8;
LOCKPIN_HOLE_SIDE_LENGTH = 4;
LOCKPIN_HOLE_SIDE_LENGTH_DIMENSION = [LOCKPIN_HOLE_SIDE_LENGTH, LOCKPIN_HOLE_SIDE_LENGTH];
HR_YELLOW = "#f7b600";
HR_BLUE = "#0056b3";
HR_RED = "#c41e3a";
HR_GREEN = "#2d7a2e";
HR_CHARCOAL = "#333333";
HR_WHITE = "#f0f0f0";
STD_UNIT_HEIGHT = 44.45;
STD_UNIT_DEPTH = 482.6;
STD_WIDTH_10INCH = 254;
STD_WIDTH_19INCH = 482.6;
STD_MOUNT_SURFACE_WIDTH = 15.875;
STD_RACK_BORE_DISTANCE_Z = 15.875;
STD_RACK_BORE_DISTANCE_MARGIN_Z = 6.35;
tolerance = TOLERANCE;
printing_layer_width = PRINTING_LAYER_WIDTH;
printing_layer_height = PRINTING_LAYER_HEIGHT;
base_unit = BASE_UNIT;
base_strength = BASE_STRENGTH;
base_chamfer = BASE_CHAMFER;
lockpin_hole_chamfer = LOCKPIN_HOLE_CHAMFER;
lockpin_hole_side_length = LOCKPIN_HOLE_SIDE_LENGTH;
lockpin_hole_side_length_dimension = LOCKPIN_HOLE_SIDE_LENGTH_DIMENSION;

module support(units=3, x_holes=false) {
    support_dimensions = [BASE_UNIT, BASE_UNIT*units, BASE_UNIT];

    difference() {

        color("darkslategray")
        cuboid(support_dimensions, chamfer=BASE_CHAMFER);

        ycopies(spacing=BASE_UNIT, n=units) {

            color("red") lock_pin_hole();
        }
        if (x_holes) {
            ycopies(spacing=BASE_UNIT, n=units) {

                color("red") rotate([0,90,0]) lock_pin_hole();
            }
        }
    }
}

module lock_pin_hole() {
    lock_pin_center_side = LOCKPIN_HOLE_SIDE_LENGTH + PRINTING_LAYER_WIDTH*2;
    lock_pin_center_dimension = [lock_pin_center_side, lock_pin_center_side];

    lock_pin_outer_side = LOCKPIN_HOLE_SIDE_LENGTH + LOCKPIN_HOLE_CHAMFER*2;
    lock_pin_outer_dimension = [lock_pin_outer_side, lock_pin_outer_side];

    lock_pin_prismoid_inner_length = BASE_UNIT/2 - LOCKPIN_HOLE_CHAMFER;
    lock_pin_prismoid_outer_length = LOCKPIN_HOLE_CHAMFER;

    module hole_half() {
        union() {
            prismoid(size1=lock_pin_center_dimension, size2=LOCKPIN_HOLE_SIDE_LENGTH_DIMENSION, h=lock_pin_prismoid_inner_length);
            translate([0, 0, lock_pin_prismoid_inner_length]) {
                prismoid(size1=LOCKPIN_HOLE_SIDE_LENGTH_DIMENSION, size2=lock_pin_outer_dimension, h=lock_pin_prismoid_outer_length);
            }
        }
    }

    hole_half();

    mirror([0, 0, 1]) {
        hole_half();
    }
}

connector_outer_side_length = BASE_UNIT + BASE_STRENGTH*2 + TOLERANCE;
arm_side_length_inner = connector_outer_side_length - BASE_STRENGTH*2;
core_to_arm_translation = BASE_UNIT;
CONNECTOR_CONFIGS = [

    [
        [true, false, false, false, false, false],
        [true, true, false, false, false, false]
    ],

    [
        [true, false, true, false, false, false],
        [true, true, true, false, false, false],
        [true, true, true, true, false, false]
    ],

    [
        [true, false, true, false, true, false],
        [true, true, true, false, true, false],
        [true, true, true, true, true, false],
        [true, true, true, true, true, true]
    ]
];
module connector(dimensions=3, directions=6, pull_through_axis="none", is_foot=false, optimal_orientation=false) {

  valid_dimensions = max(1, min(3, dimensions));

  min_directions = valid_dimensions == 1 ? 1 : valid_dimensions;
  max_directions = valid_dimensions * 2;

  valid_directions = max(min_directions, min(max_directions, directions));

  config = CONNECTOR_CONFIGS[valid_dimensions - 1][valid_directions - min_directions];

  difference() {

    union() {
      if (valid_directions > 4) {

        rotation_1 = optimal_orientation ? [-(180 - acos(1/sqrt(3))),0,0] : [0,0,0];
        rotation_2 = optimal_orientation ? [0,0,45] : [0,0,0];
        rotate(rotation_1) rotate(rotation_2)
        difference() {
          union() {
            connector_raw(config, is_foot);
            print_interface_3d();
          }
          pull_through_hole(pull_through_axis, is_foot);
        }
      } else if (valid_directions == 4 && valid_dimensions == 2) {
        rotation = optimal_orientation ? [0,-135,0] : [0,0,0];
        rotate(rotation)
        difference() {
          connector_raw(config, is_foot);
          pull_through_hole(pull_through_axis, is_foot);
        }

      } else {

        rotation = optimal_orientation ? [90,-45,0] : [0,0,0];
        rotate(rotation)
        difference() {
          intersection() {
            connector_raw(config, is_foot);
            print_interface_base();
          }
          pull_through_hole(pull_through_axis, is_foot);
        }
      }
    }
  }
}

module connector_raw(config, is_foot=false) {
  difference() {

    union() {

      connectorCore();

      if (config[0]) translate([0, 0, core_to_arm_translation]) connectorArmOuter(is_foot);
      if (config[1]) translate([0, 0, -core_to_arm_translation]) rotate([180, 0, 0]) connectorArmOuter();
      if (config[2]) translate([core_to_arm_translation, 0, 0]) rotate([0, 90, 0]) connectorArmOuter();
      if (config[3]) translate([-core_to_arm_translation, 0, 0]) rotate([0, -90, 0]) connectorArmOuter();
      if (config[4]) translate([0, core_to_arm_translation, 0]) rotate([-90, 0, 0]) connectorArmOuter();
      if (config[5]) translate([0, -core_to_arm_translation, 0]) rotate([90, 0, 0]) connectorArmOuter();
    }

    if (config[0] && !is_foot) translate([0, 0, core_to_arm_translation]) connectorArmInner();
    if (config[1]) translate([0, 0, -core_to_arm_translation]) rotate([180, 0, 0]) connectorArmInner();
    if (config[2]) translate([core_to_arm_translation, 0, 0]) rotate([0, 90, 0]) connectorArmInner();
    if (config[3]) translate([-core_to_arm_translation, 0, 0]) rotate([0, -90, 0]) connectorArmInner();
    if (config[4]) translate([0, core_to_arm_translation, 0]) rotate([-90, 0, 0]) connectorArmInner();
    if (config[5]) translate([0, -core_to_arm_translation, 0]) rotate([90, 0, 0]) connectorArmInner();
  }
}

module connectorArmOuter(is_foot=false) {

  arm_dimensions_outer = [connector_outer_side_length, connector_outer_side_length, BASE_UNIT];
  arm_side_length_inner = connector_outer_side_length - BASE_STRENGTH*2;
  arm_dimensions_inner = [arm_side_length_inner, arm_side_length_inner, BASE_UNIT];

  difference() {
    color(HR_YELLOW) cuboid(arm_dimensions_outer, chamfer=BASE_CHAMFER,except=BOTTOM);
    if(!is_foot){
      color(HR_RED) rotate([90, 0, 0]) cuboid([LOCKPIN_HOLE_SIDE_LENGTH, LOCKPIN_HOLE_SIDE_LENGTH, connector_outer_side_length], chamfer=-LOCKPIN_HOLE_CHAMFER);
      color(HR_RED) rotate([90, 0, 90]) cuboid([LOCKPIN_HOLE_SIDE_LENGTH, LOCKPIN_HOLE_SIDE_LENGTH, connector_outer_side_length], chamfer=-LOCKPIN_HOLE_CHAMFER);
    }
  }
}

module connectorArmInner() {

  arm_dimensions_inner = [arm_side_length_inner, arm_side_length_inner, BASE_UNIT];
  color(HR_GREEN)
  cuboid(arm_dimensions_inner, chamfer=BASE_CHAMFER,edges=BOTTOM);
}

module connectorCore() {
  core_dimensions = [connector_outer_side_length, connector_outer_side_length, connector_outer_side_length];
  color(HR_BLUE)
  cuboid(core_dimensions, chamfer=BASE_CHAMFER);
}

module print_interface_3d() {

  side_length = BASE_UNIT - TOLERANCE/2 - BASE_STRENGTH/2;

  translation = connector_outer_side_length/2 - BASE_CHAMFER;
  points = [
    [0, 0, 0],
    [side_length, 0, 0],
    [0, side_length, 0],
    [0, 0, side_length]
  ];

  faces = [
    [0, 2, 1],
    [0, 1, 3],
    [0, 3, 2],
    [1, 2, 3]
  ];

  color(HR_CHARCOAL)
  translate([translation, translation, translation])
  polyhedron(points=points, faces=faces, convexity=2);
}

module print_interface_base() {
  base_height = BASE_UNIT * 3;
  side_length = connector_outer_side_length *2;
  chamfer = BASE_CHAMFER * 3;

  color(HR_CHARCOAL)

  translate([connector_outer_side_length/2,connector_outer_side_length/2,0])
  cuboid([side_length, side_length, base_height], chamfer=chamfer, edges=LEFT+FRONT);
}

module pull_through_hole(axis="none", is_foot=false) {

  hole_length = BASE_UNIT * 3;
  hole_dimensions = [hole_length, arm_side_length_inner, arm_side_length_inner];

  color(HR_WHITE)
  if (axis == "y") {
    rotate([0, 0, 90])
    cuboid(hole_dimensions);
  } else if (axis == "z" && !is_foot) {
    rotate([0, -90, 0])
    cuboid(hole_dimensions);
  } else if (axis == "x") {
    cuboid(hole_dimensions);
  }
}
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

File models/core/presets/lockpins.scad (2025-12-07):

// HomeRacker - Lock Pin Release Variants
//
// This is an opinionated collection of useful lock pin variants for
// export and release. Creates a grid pattern of lock pins for efficient printing.

include <../main.scad>

/* [General] */
grid = 5; // Total number of lock pins to create

/* [Hidden] */
$fn = 100;

// Grid configuration
spacing = [ grip_width + PRINTING_LAYER_WIDTH * 2, BASE_UNIT + BASE_STRENGTH * 2 + TOLERANCE + PRINTING_LAYER_WIDTH  * 2 + grip_base_length];

module lockpins_grid(grid=10, grip_type="standard") {
    grid_copies(spacing, n=grid) {
        color(HR_YELLOW)
        lockpin(grip_type=grip_type);
    }
}

// Standard grip grid (50 pins)
// lockpins_grid(grid=grid, grip_type="standard");

// Uncomment for no-grip variant:
lockpins_grid(grid=grid, grip_type="no_grip");

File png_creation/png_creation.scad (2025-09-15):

/* [SVG Parameters] */
// Amount to "thicken" the SVG shape in mm. This helps to fill small gaps.
thicken_amount = 0.1; // [0:0.1:5]

// Height of the extrusion in mm
extrusion_height = 20; // [1:1:100]

/* [Global Settings] */
$fn = 100;

// --- Implementation ---

linear_extrude(height = extrusion_height) {
    offset(delta = thicken_amount) {
        import("spitzzangerl.svg", center = true);
    }
}

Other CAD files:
models/core/parts/lockpin.scad
models/core/main.scad
models/core/makerworld/connector.scad
models/core/makerworld/support.scad
models/core/parts/connector.scad
models/core/parts/support.scad
models/core/presets/connectors.scad
models/core/presets/supports.scad
models/core/test/connector.scad
models/core/test/lockpin.scad
models/core/test/support.scad
models/flexmount/flexmount.scad
models/gridfinity/base.scad
models/gridfinity/makerworld/baseplate.scad
models/gridfinity/makerworld/binbase.scad
models/gridfinity/parts/baseplate.scad
models/gridfinity/parts/binbase.scad
models/rackmount_ears/rackmount_ears.scad
models/wallmount/wallmount.scad

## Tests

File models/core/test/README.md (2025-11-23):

# Core Tests

This directory contains test files for the HomeRacker core system.

## Purpose

Test files in this directory are automatically discovered and validated by the test suite:
```bash
./cmd/test/test-models.sh
```

## Test Files

- **`connector.scad`**: Tests the connector module with default parameters
- **`support.scad`**: Tests the support module with default parameters

## Adding Tests

To add a new test:
1. Create a `.scad` file in this directory
2. Include the core library: `include <../main.scad>`
3. Render a specific test case with chosen parameters
4. Run `./cmd/test/test-models.sh` to validate

Each test file should produce a valid, renderable 3D object.

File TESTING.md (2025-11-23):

# Testing Guide

## General Testing Principles

Always test changes before committing:
- **Use existing test scripts** in `/cmd/test/` when available
- **Write simple tests** if none exist (bash scripts, Python tests, or manual verification steps)
- **Document test steps** in commit messages or PR descriptions

## Renovate Configuration Testing

When modifying `renovate.json5`, always test changes before merging to prevent incorrect PRs.

### Workflow

1. **Create feature branch**
   ```bash
   git checkout -b fix/renovate-<description>
   ```

2. **Make changes and commit**
   ```bash
   git add renovate.json5
   git commit -m "fix(renovate): <description>"
   ```

3. **Push to remote** (required for testing)
   ```bash
   git push -u origin fix/renovate-<description>
   ```

4. **Test locally**
   ```bash
   ./cmd/test/test-renovate-local.sh
   ```

5. **Validate output**
   - Check that dependencies are detected correctly
   - Verify version extraction matches expected format
   - Confirm updates are grouped as intended

### Example: Testing OpenSCAD Updates

```bash
# Checkout the branch you want to test
git checkout fix/renovate-openscad-separate-extractors
./cmd/test/test-renovate-local.sh
```

Expected output should show:
- `OpenSCAD-Windows`: version without `.ai` suffix
- `OpenSCAD-Linux`: version with `.ai` suffix preserved

### Example: Testing Grouping and Automerge

```bash
# Test pre-commit hooks grouping
git checkout renovate-pre-commit
./cmd/test/test-renovate-local.sh
```

Expected output should show:
- **Single branch** `renovate/pre-commit-hooks` containing all pre-commit hook updates
- Both **major and minor** updates combined (verify `separateMajorMinor: false`)
- `"automerge": true` in the branch configuration
- No separate `renovate/major-pre-commit-hooks` branch

### Why Remote Push is Required

Renovate test fetches from GitHub, so changes must exist remotely before testing validates them.

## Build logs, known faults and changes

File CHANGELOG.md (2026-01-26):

# Changelog

## [1.7.2](https://github.com/kellerlabs/homeracker/compare/homeracker-v1.7.1...homeracker-v1.7.2) (2026-01-25)

### 📦 Dependencies

* update belfryscad/bosl2 digest to a9f31f0 ([#208](https://github.com/kellerlabs/homeracker/issues/208)) ([5d20a0e](https://github.com/kellerlabs/homeracker/commit/5d20a0ec795063ec73040c2f65c8d6971b908429))
* update camunda/infra-global-github-actions digest to 8a60c6a ([#209](https://github.com/kellerlabs/homeracker/issues/209)) ([76887ec](https://github.com/kellerlabs/homeracker/commit/76887ec5bdae866c5c393db2bbcf7385a1faf9c1))
* update dependency openscad-windows to v2026.01.19 ([#210](https://github.com/kellerlabs/homeracker/issues/210)) ([c57df5a](https://github.com/kellerlabs/homeracker/commit/c57df5adcf7967cf6e21b5fa8d622673bd7fc38e))
* update dependency openscad-windows to v2026.01.25 ([#211](https://github.com/kellerlabs/homeracker/issues/211)) ([e4f6407](https://github.com/kellerlabs/homeracker/commit/e4f640767a17eba1c7e8dd5efc208515cc1b47cf))

## [1.7.1](https://github.com/kellerlabs/homeracker/compare/homeracker-v1.7.0...homeracker-v1.7.1) (2026-01-18)

### 📦 Dependencies

* update belfryscad/bosl2 digest to 7e5dfe5 ([#200](https://github.com/kellerlabs/homeracker/issues/200)) ([af1350a](https://github.com/kellerlabs/homeracker/commit/af1350a3c92eb5295277bcc289a6d576c6c32162))
* update camunda/infra-global-github-actions digest to 5f8949d ([#201](https://github.com/kellerlabs/homeracker/issues/201)) ([dd027f1](https://github.com/kellerlabs/homeracker/commit/dd027f163ee5e57d0eaa9fdc0a89c3b3df54135c))
* update dependency openscad-windows to v2026.01.18 ([#202](https://github.com/kellerlabs/homeracker/issues/202)) ([b7098c9](https://github.com/kellerlabs/homeracker/commit/b7098c985831d87701509cb4d5e29b9e9f194405))
* update pre-commit hooks ([#203](https://github.com/kellerlabs/homeracker/issues/203)) ([bfe0047](https://github.com/kellerlabs/homeracker/commit/bfe0047ae5cb97f137079cc69df0720118971be5))

### ♻️ Code Refactoring

* update repository references from kellervater to kellerlabs ([#198](https://github.com/kellerlabs/homeracker/issues/198)) ([8e5717b](https://github.com/kellerlabs/homeracker/commit/8e5717bf0ee1b8b2e06d247fccb83eced79f06ee))

## [1.7.0](https://github.com/kellervater/homeracker/compare/homeracker-v1.6.0...homeracker-v1.7.0) (2026-01-12)

### ✨ Features

* **gridfinity:** baseplate & binbase modules ([#187](https://github.com/kellervater/homeracker/issues/187)) ([827c041](https://github.com/kellervater/homeracker/commit/827c041989116eb15a5eed1e6ee8c0365037b0f3))

### 📦 Dependencies

* update belfryscad/bosl2 digest to ed3afe3 ([#188](https://github.com/kellervater/homeracker/issues/188)) ([ab4c7c7](https://github.com/kellervater/homeracker/commit/ab4c7c71ebacf24a18737acfdc579bdc5ae1a4db))
* update camunda/infra-global-github-actions digest to a708558 ([#189](https://github.com/kellervater/homeracker/issues/189)) ([b674105](https://github.com/kellervater/homeracker/commit/b6741058e993a9339e55cd43f1b3b15fea641f53))
* update pre-commit hook renovatebot/pre-commit-hooks to v42.76.4 ([#190](https://github.com/kellervater/homeracker/issues/190)) ([8417370](https://github.com/kellervater/homeracker/commit/8417370c3f9a8645f475bd4ae8bbff5bb15ffe26))
* update pre-commit hook renovatebot/pre-commit-hooks to v42.76.5 ([#192](https://github.com/kellervater/homeracker/issues/192)) ([859dfd6](https://github.com/kellervater/homeracker/commit/859dfd62cfa6b475130568274b051cbf55157aa7))
* update pre-commit hook renovatebot/pre-commit-hooks to v42.78.0 ([#193](https://github.com/kellervater/homeracker/issues/193)) ([92db61f](https://github.com/kellervater/homeracker/commit/92db61f778b6ac51ca16ca33321850b6718fa1fe))
* update pre-commit hook renovatebot/pre-commit-hooks to v42.78.1 ([#194](https://github.com/kellervater/homeracker/issues/194)) ([a217589](https://github.com/kellervater/homeracker/commit/a2175890a86c2bf8d3e12063cfb2eb96f1cbf9f7))

## [1.6.0](https://github.com/kellervater/homeracker/compare/homeracker-v1.5.2...homeracker-v1.6.0) (2026-01-04)

### ✨ Features

* **core:** add extended grip type ([#173](https://github.com/kellervater/homeracker/issues/173)) ([7e4b27a](https://github.com/kellervater/homeracker/commit/7e4b27a5ea451d1894c634b91379e17961355494))

### 📦 Dependencies

* update camunda/infra-global-github-actions digest to 084e5ba ([#184](https://github.com/kellervater/homeracker/issues/184)) ([0be0d09](https://github.com/kellervater/homeracker/commit/0be0d090b3cb1859dadf3ea482bbb1ee859e8814))
* update camunda/infra-global-github-actions digest to 309fedf ([#180](https://github.com/kellervater/homeracker/issues/180)) ([e627303](https://github.com/kellervater/homeracker/commit/e62730314923241746caf83dc3cb863c6208d9d3))
* update dependency openscad-windows to v2026.01.03 ([#186](https://github.com/kellervater/homeracker/issues/186)) ([fce4a5a](https://github.com/kellervater/homeracker/commit/fce4a5ae4af4324405e63a119a5204fa941819ac))
* update openscad nightly to v2026 ([#182](https://github.com/kellervater/homeracker/issues/182)) ([45efd5c](https://github.com/kellervater/homeracker/commit/45efd5c58e53859d94c5af7bfe08a8f8bc75003e))
* update pre-commit hook renovatebot/pre-commit-hooks to v42.70.3 ([#183](https://github.com/kellervater/homeracker/issues/183)) ([b391b09](https://github.com/kellervater/homeracker/commit/b391b09e8792cac893337f6f35e169d134289505))
* update pre-commit hook renovatebot/pre-commit-hooks to v42.71.0 ([#185](https://github.com/kellervater/homeracker/issues/185)) ([bf326b5](https://github.com/kellervater/homeracker/commit/bf326b5ad0e5e350d9ea24d9fe13f0ac2709569c))
* update pre-commit hooks ([#181](https://github.com/kellervater/homeracker/issues/181)) ([4748876](https://github.com/kellervater/homeracker/commit/4748876a19e5ff0437b95e4f909528d67167b7d6))

### 📚 Documentation

* add Community section to README ([#175](https://github.com/kellervater/homeracker/issues/175)) ([71dbee8](https://github.com/kellervater/homeracker/commit/71dbee8386a1766a161bf7d299dba8ba229d6cd9))
* pre-commit.dev -&gt; pre-commit.com fixes ([#179](https://github.com/kellervater/homeracker/issues/179)) ([3e61b1a](https://github.com/kellervater/homeracker/commit/3e61b1aa1029c709d934c08362df6e550f75ffc7))
* updated CONTRIBUTING.md minor inaccuracies ([#178](https://github.com/kellervater/homeracker/issues/178)) ([a45cc3c](https://github.com/kellervater/homeracker/commit/a45cc3c98a2ce2346f5c96cf05779217950214c2))

## [1.5.2](https://github.com/kellervater/homeracker/compare/homeracker-v1.5.1...homeracker-v1.5.2) (2025-12-28)

### 📦 Dependencies

* update belfryscad/bosl2 digest to 79d836c ([#169](https://github.com/kellervater/homeracker/issues/169)) ([5e75f46](https://github.com/kellervater/homeracker/commit/5e75f46fc0196b617b909f34e0488b0e243342df))
* update camunda/infra-global-github-actions digest to ac7a12d ([#164](https://github.com/kellervater/homeracker/issues/164)) ([60a1514](https://github.com/kellervater/homeracker/commit/60a15146ce7128833b954479e224da9b5e7ec3d7))
* update openscad nightly ([#165](https://github.com/kellervater/homeracker/issues/165)) ([7f8746c](https://github.com/kellervater/homeracker/commit/7f8746c1c923934d4e4eec0a87b140849aa55919))
* update openscad nightly ([#168](https://github.com/kellervater/homeracker/issues/168)) ([fe441bd](https://github.com/kellervater/homeracker/commit/fe441bd91f4019676d52981e70cb88ca8a09ca56))
* update openscad nightly ([#171](https://github.com/kellervater/homeracker/issues/171)) ([fccf876](https://github.com/kellervater/homeracker/commit/fccf87602d08aef6c9aa0ea41d6ad1353ca9eb93))
* update pre-commit hook renovatebot/pre-commit-hooks to v42.66.11 ([#172](https://github.com/kellervater/homeracker/issues/172)) ([cf56f84](https://github.com/kellervater/homeracker/commit/cf56f84f44ed5b869e46a79fd9df819897ef7f4c))
* update pre-commit hook renovatebot/pre-commit-hooks to v42.66.8 ([#166](https://github.com/kellervater/homeracker/issues/166)) ([56a2669](https://github.com/kellervater/homeracker/commit/56a2669e909af0afd5d43c3c8237c72479b3e366))
* update pre-commit hook renovatebot/pre-commit-hooks to v42.66.9 ([#170](https://github.com/kellervater/homeracker/issues/170)) ([296d234](https://github.com/kellervater/homeracker/commit/296d234d0501d412dae093af7f041ad76728975d))

## [1.5.1](https://github.com/kellervater/homeracker/compare/homeracker-v1.5.0...homeracker-v1.5.1) (2025-12-20)

### 📦 Dependencies

* update belfryscad/bosl2 digest to 9312b5b ([#158](https://github.com/kellervater/homeracker/issues/158)) ([f123eea](https://github.com/kellervater/homeracker/commit/f123eea015c66f17e413a94abb9d87dcbf6291dd))
* update camunda/infra-global-github-actions digest to 4b7639e ([#159](https://github.com/kellervater/homeracker/issues/159)) ([2a759cd](https://github.com/kellervater/homeracker/commit/2a759cd557f3c12817ea2cdcb41e9d890c3ebf93))
* update openscad nightly ([#161](https://github.com/kellervater/homeracker/issues/161)) ([c22aa62](https://github.com/kellervater/homeracker/commit/c22aa62536b6664a6aa112ac5424bc39b5593163))
* update pre-commit hook renovatebot/pre-commit-hooks to v42.64.1 ([#162](https://github.com/kellervater/homeracker/issues/162)) ([b26dfda](https://github.com/kellervater/homeracker/commit/b26dfda6ac6974b0426f7ef77522dd384e287f79))

### 📚 Documentation

* **fix:** conventional commits bump ([62b319b](https://github.com/kellervater/homeracker/commit/62b319bc7870d9c2f8cfe9b0ef14e46ed4c1020f))

## [1.5.0](https://github.com/kellervater/homeracker/compare/homeracker-v1.4.0...homeracker-v1.5.0) (2025-12-15)

### ✨ Features

* **img:** added HomeRacker Logo svgs ([4f264a9](https://github.com/kellervater/homeracker/commit/4f264a9f3896206b0cd6e1778304710921764948))
* **scadm:** add --version flag ([#140](https://github.com/kellervater/homeracker/issues/140)) ([5a7d98c](https://github.com/kellervater/homeracker/commit/5a7d98cfd33c36f9d6e1df95181c42c5c6195b2f))

### 🐛 Bug Fixes

* **core:** improve print orientation for bed slingers. ([#144](https://github.com/kellervater/homeracker/issues/144)) ([e2177c9](https://github.com/kellervater/homeracker/commit/e2177c9099224fcdb8dd55217180ecae1813d06e))
* **renovate:** add custom manager for homeracker-vX.Y.Z tags in scadm.json ([#155](https://github.com/kellervater/homeracker/issues/155)) ([8155b0f](https://github.com/kellervater/homeracker/commit/8155b0fc4052376a1fc71080075968b74883be8c))

### 📦 Dependencies

* update actions/upload-artifact action to v6 ([#150](https://github.com/kellervater/homeracker/issues/150)) ([96584a7](https://github.com/kellervater/homeracker/commit/96584a7d4334131d5976ff8568da9e49635ae40e))
* update belfryscad/bosl2 digest to 7c6b1da ([#151](https://github.com/kellervater/homeracker/issues/151)) ([13ea9ad](https://github.com/kellervater/homeracker/commit/13ea9ad77a6fbc5ec30240231bc05a96f26bec19))
* update belfryscad/bosl2 digest to 961ed6d ([#146](https://github.com/kellervater/homeracker/issues/146)) ([c0687da](https://github.com/kellervater/homeracker/commit/c0687da15d64b59bedc0d07cca2a9727f009c6ed))
* update camunda/infra-global-github-actions digest to 1f5a9ae ([#147](https://github.com/kellervater/homeracker/issues/147)) ([0fcea2e](https://github.com/kellervater/homeracker/commit/0fcea2e0c2d97c69cb2695ad4a26862cdcebd86e))
* update camunda/infra-global-github-actions digest to 39cfd35 ([#153](https://github.com/kellervater/homeracker/issues/153)) ([2c32c2a](https://github.com/kellervater/homeracker/commit/2c32c2adf3f13127df96846ebfd52edbf22f021e))
* update openscad nightly ([#148](https://github.com/kellervater/homeracker/issues/148)) ([29756dd](https://github.com/kellervater/homeracker/commit/29756ddfd902c61add8094f56d17e8b709789eda))
* update pre-commit hook renovatebot/pre-commit-hooks to v42.52.2 ([#149](https://github.com/kellervater/homeracker/issues/149)) ([2e860d9](https://github.com/kellervater/homeracker/commit/2e860d95f4f9ea19556a13d06e45731d77c8f3d9))
* update pre-commit hook renovatebot/pre-commit-hooks to v42.52.6 ([#152](https://github.com/kellervater/homeracker/issues/152)) ([4865ab4](https://github.com/kellervater/homeracker/commit/4865ab4d94a00480748720f689d76bc6f3a9d1cb))
* update pre-commit hook renovatebot/pre-commit-hooks to v42.52.8 ([#156](https://github.com/kellervater/homeracker/issues/156)) ([8fbe3af](https://github.com/kellervater/homeracker/commit/8fbe3af2ec4b697a1016c874ea95805b317ad54a))

### 📚 Documentation

* **img:** svg logo links ([3ddbd86](https://github.com/kellervater/homeracker/commit/3ddbd86a0823531e71b7642893b88962b2d80bdb))

## [1.4.0](https://github.com/kellervater/homeracker/compare/homeracker-v1.3.1...homeracker-v1.4.0) (2025-12-08)

### ✨ Features

* **scadm:** add Python extension support to vscode command ([#133](https://github.com/kellervater/homeracker/issues/133)) ([0bee683](https://github.com/kellervater/homeracker/commit/0bee683232593428290fe116fd7af9ce2c732816))
* **scadm:** add vscode command for extension management ([#131](https://github.com/kellervater/homeracker/issues/131)) ([573c9dd](https://github.com/kellervater/homeracker/commit/573c9ddbbe420c0bd4f1631e240a54e9bac5d5d3))

### 📦 Dependencies

* update pre-commit hooks ([#134](https://github.com/kellervater/homeracker/issues/134)) ([e18d974](https://github.com/kellervater/homeracker/commit/e18d9743e5ca4f4ebfc14039208648d71195361a))

## [1.3.1](https://github.com/kellervater/homeracker/compare/homeracker-v1.3.0...homeracker-v1.3.1) (2025-12-07)

### 📦 Dependencies

* update belfryscad/bosl2 digest to b47d5eb ([#122](https://github.com/kellervater/homeracker/issues/122)) ([6d63741](https://github.com/kellervater/homeracker/commit/6d637414d855b4aff31c760fb5627feb256111d4))
* update dependency python to 3.14 ([#128](https://github.com/kellervater/homeracker/issues/128)) ([a26eace](https://github.com/kellervater/homeracker/commit/a26eace0949c2188bedcacb7bf1beb8793160e12))
* update github actions to v6 (major) ([#129](https://github.com/kellervater/homeracker/issues/129)) ([0462e90](https://github.com/kellervater/homeracker/commit/0462e90ad284e5c138e7acf234ffa9f5f605f470))
* update openscad nightly ([#124](https://github.com/kellervater/homeracker/issues/124)) ([b12fc92](https://github.com/kellervater/homeracker/commit/b12fc92673c85ecd519e5875aed2c68d55a3a2ad))

### 🔄 CI/CD

* **renovate:** group GHA prs ([9824210](https://github.com/kellervater/homeracker/commit/9824210fcd2746ef4c4a186e024ff130591725db))

### ♻️ Code Refactoring

* uppercase all constants with backward compatibility ([#130](https://github.com/kellervater/homeracker/issues/130)) ([9076d73](https://github.com/kellervater/homeracker/commit/9076d7303361758cdb3b575f80d578212dcccdda))

## [1.3.0](https://github.com/kellervater/homeracker/compare/homeracker-v1.2.0...homeracker-v1.3.0) (2025-12-07)

### ✨ Features

* add overlay logo ([3a7f1eb](https://github.com/kellervater/homeracker/commit/3a7f1ebb1b8021bae5df22993788e84048828501))
* add ruby & intentionally downgrade versions ([9fe7a61](https://github.com/kellervater/homeracker/commit/9fe7a614172d33807ef0971de4f9d8fdc9d4f5f2))
* added license ([f022f04](https://github.com/kellervater/homeracker/commit/f022f047a8f26d04f4f4ff772501f41631d5040d))
* asdf installation ([2b9e906](https://github.com/kellervater/homeracker/commit/2b9e906e72e55ded040e7ba683f0f8dca2a4183c))
* bunch of raw data ([7b4590c](https://github.com/kellervater/homeracker/commit/7b4590c2de6d188a7fb4a3c5e9acf51fd706d44f))
* **ci:** add CI workflow to validate OpenSCAD model rendering ([#48](https://github.com/kellervater/homeracker/issues/48)) ([030e5ca](https://github.com/kellervater/homeracker/commit/030e5ca20ddf464dca76964dd9a082dcf9eac60e))
* **copilot:** added 1st instruction draft ([d9eac22](https://github.com/kellervater/homeracker/commit/d9eac222e419163c7d192041336d1bdf5033aa0c))
* core export script ([27213d9](https://github.com/kellervater/homeracker/commit/27213d9d50b7af9723158aff833b2ee3181a218e))
* **core:** added more pull-through feet ([#85](https://github.com/kellervater/homeracker/issues/85)) ([d4461c4](https://github.com/kellervater/homeracker/commit/d4461c4f6841d9316901127a4e21240775c7493b))
* **core:** provide HomeRacker core as OpenSCAD library ([#32](https://github.com/kellervater/homeracker/issues/32)) ([a50e774](https://github.com/kellervater/homeracker/commit/a50e774507f9102238b0d63465a5388bbf876149))
* favicon ([e91dffa](https://github.com/kellervater/homeracker/commit/e91dffa6cc961de2977d045494f1ce6477faed0a))
* flexmount bracket ([98e19ef](https://github.com/kellervater/homeracker/commit/98e19efa60837c36e77f0a96e2a7099e3447ec06))
* gridfinity baseplate ([4c7c8f2](https://github.com/kellervater/homeracker/commit/4c7c8f2dc3b2ea4e46e975c161c5cbda4e3c0698))
* implement automated releases with Camunda GitHub actions ([#49](https://github.com/kellervater/homeracker/issues/49)) ([62691cb](https://github.com/kellervater/homeracker/commit/62691cb3bbf69b4f0de370c3fbd6fbd1b0859674))
* implement custom dependency manager and renovate preset ([#106](https://github.com/kellervater/homeracker/issues/106)) ([96393d1](https://github.com/kellervater/homeracker/commit/96393d1e91c657abbbfc03465e0c089080300346))
* jpg to png to svg ([099b754](https://github.com/kellervater/homeracker/commit/099b754156948867b8e0ea572d85e2b45482394e))
* **rackmount_ears:** asymetry slider ([#13](https://github.com/kellervater/homeracker/issues/13)) ([ebeb258](https://github.com/kellervater/homeracker/commit/ebeb258d60adb0c36ee70117b69d417d8d49e0e4))
* **rackmount_ears:** option to show actual ear distance ([beb5f39](https://github.com/kellervater/homeracker/commit/beb5f39722bc5680f79e917926e8de0b1e80e40d))
* **rackmount-ears:** initial commit ([482484c](https://github.com/kellervater/homeracker/commit/482484cb8316df7ecc114230172e613bbe0bd46e))
* scad installer ([#41](https://github.com/kellervater/homeracker/issues/41)) ([688d7a3](https://github.com/kellervater/homeracker/commit/688d7a3535459f923bc4d0471bade288b184d1d1))
* set theme ([d80e7ee](https://github.com/kellervater/homeracker/commit/d80e7ee17e425d45652ccebd67f3e2bf997169a2))
* **shelf:** python exporter ([a5bad40](https://github.com/kellervater/homeracker/commit/a5bad400827f257ce0c43e125242ff8274f4074b))
* wallmount ([#14](https://github.com/kellervater/homeracker/issues/14)) ([a1c8d11](https://github.com/kellervater/homeracker/commit/a1c8d11b6afb284a4d9c5a9db20a4ae25d2b3b18))

### 🐛 Bug Fixes

* **ci:** release please config ([#55](https://github.com/kellervater/homeracker/issues/55)) ([9c95988](https://github.com/kellervater/homeracker/commit/9c9598895b12ca43cc1b1610b7ca83af67040708))
* emojis ([35f0caa](https://github.com/kellervater/homeracker/commit/35f0caa9d1c8654bf940bb42eefeaca432976d93))
* favicon ([91a43c8](https://github.com/kellervater/homeracker/commit/91a43c8259ecb59a6d87839654a0f5d72916a3ed))
* logo details ([34cd659](https://github.com/kellervater/homeracker/commit/34cd65917727176b8c6228104c2c1941341a05a1))
* logo transparency ([bc80d1e](https://github.com/kellervater/homeracker/commit/bc80d1e65f0a208370250984faaf87915f97c45f))
* makerworld link ([c4bc57d](https://github.com/kellervater/homeracker/commit/c4bc57de6d306e34419b8ad39d661ec4cebbcf68))
* move release-please config files to .github/config ([#53](https://github.com/kellervater/homeracker/issues/53)) ([5a423bc](https://github.com/kellervater/homeracker/commit/5a423bc23380d0bffe726a24429819f817186d52))
* path for openscad-render.sh ([#108](https://github.com/kellervater/homeracker/issues/108)) ([aea790c](https://github.com/kellervater/homeracker/commit/aea790ca856dfee800c1368a178959c7a3900f26))
* **rackmountears:** sane defaults ([a1a6777](https://github.com/kellervater/homeracker/commit/a1a6777aea8052ad672fe6c37afcb5b9a0a13646))
* **renovate:** openSCAD nightly versions ([#60](https://github.com/kellervater/homeracker/issues/60)) ([5e4e70d](https://github.com/kellervater/homeracker/commit/5e4e70d91e7e57b964c8d32627b85fdfee2a5708))
* **renovate:** preserve .ai suffix for Linux OpenSCAD versions ([#63](https://github.com/kellervater/homeracker/issues/63)) ([a391cd3](https://github.com/kellervater/homeracker/commit/a391cd3bb30043bc8b1c39a97b9f6facc43c3989))
* **renovate:** use currentDigest for BOSL2 ([#92](https://github.com/kellervater/homeracker/issues/92)) ([99704a5](https://github.com/kellervater/homeracker/commit/99704a500f9154ea270552db3b0274999a8649c7))
* **renovate:** use full git URL for BOSL2 automerge matching ([#96](https://github.com/kellervater/homeracker/issues/96)) ([f7997e7](https://github.com/kellervater/homeracker/commit/f7997e7e3ebdff9b82ddae7e91f4955a352c5fb7))
* set executable bit on scripts for pre-commit. ([#111](https://github.com/kellervater/homeracker/issues/111)) ([9549aca](https://github.com/kellervater/homeracker/commit/9549aca0daad4b070909e1faebf2a87d51cd10ff))
* transparent favicon ([631ef6e](https://github.com/kellervater/homeracker/commit/631ef6e837eb892209c4c0c188415f29fadf875d))
* **unimount:** typo ([b5508af](https://github.com/kellervater/homeracker/commit/b5508af9d36289f1452a2cb9a734a6c1ec12f7d5))

### 📦 Dependencies

* **renovate:** update dependency asdf-vm/asdf to v0.16.7 ([#2](https://github.com/kellervater/homeracker/issues/2)) ([96ab0b6](https://github.com/kellervater/homeracker/commit/96ab0b62fe365571c4ce620f2d79adece32615e0))
* **renovate:** update dependency pre-commit to v4.2.0 ([#4](https://github.com/kellervater/homeracker/issues/4)) ([e7e6848](https://github.com/kellervater/homeracker/commit/e7e68480393665c7c8ecbe626cc9d25cde7a8d4b))
* update actions/checkout action to v5 ([#54](https://github.com/kellervater/homeracker/issues/54)) ([405cd76](https://github.com/kellervater/homeracker/commit/405cd76e23cdb7dc2db850533bd16f64f6ff13c2))
* update actions/checkout action to v6 ([#76](https://github.com/kellervater/homeracker/issues/76)) ([82c90c4](https://github.com/kellervater/homeracker/commit/82c90c4fd9ad97d152d13531b9503146d840a4c9))
* update actions/create-github-app-token action to v2 ([#52](https://github.com/kellervater/homeracker/issues/52)) ([536396f](https://github.com/kellervater/homeracker/commit/536396f6a5c69f201b9220aa692426a66365d29a))
* update actions/setup-python action to v6 ([#82](https://github.com/kellervater/homeracker/issues/82)) ([a77c738](https://github.com/kellervater/homeracker/commit/a77c7382471e3549f6b762b6d73b9425de5490c0))
* update actions/upload-artifact action to v5 ([#57](https://github.com/kellervater/homeracker/issues/57)) ([c403c66](https://github.com/kellervater/homeracker/commit/c403c66ecd8d381f67c4eac8a29dd8875b5dd30a))
* update belfryscad/bosl2 digest to 266792b ([#95](https://github.com/kellervater/homeracker/issues/95)) ([a57d100](https://github.com/kellervater/homeracker/commit/a57d1004ee25e987641de28c9ae30f738933300f))
* update belfryscad/bosl2 digest to 44e0c4e ([#114](https://github.com/kellervater/homeracker/issues/114)) ([e0c01ba](https://github.com/kellervater/homeracker/commit/e0c01ba6b7228fac4c63e640e96d4b1e68c1c531))
* update belfryscad/bosl2 digest to b47d5eb ([#119](https://github.com/kellervater/homeracker/issues/119)) ([eb4c13a](https://github.com/kellervater/homeracker/commit/eb4c13a09fb68a8201c8a54a52fa638275dbd4ef))
* update camunda/infra-global-github-actions digest to 302d4ca ([#115](https://github.com/kellervater/homeracker/issues/115)) ([0ee258f](https://github.com/kellervater/homeracker/commit/0ee258fbb28ddd1fa27c91a8259a0163f4d38f26))
* update camunda/infra-global-github-actions digest to 83dd377 ([#80](https://github.com/kellervater/homeracker/issues/80)) ([3c03342](https://github.com/kellervater/homeracker/commit/3c033423a1ebbcd80f5afd33f7c1e85c1b95b17d))
* update camunda/infra-global-github-actions digest to 92fe1f4 ([#74](https://github.com/kellervater/homeracker/issues/74)) ([abd04ce](https://github.com/kellervater/homeracker/commit/abd04ce0516324babc7df387abd06333b7fdf00a))
* update camunda/infra-global-github-actions digest to b0fe528 ([#104](https://github.com/kellervater/homeracker/issues/104)) ([03d3cd6](https://github.com/kellervater/homeracker/commit/03d3cd64df99b8d7470c6d64f297f18d0559d1f6))
* update camunda/infra-global-github-actions digest to b80b223 ([#90](https://github.com/kellervater/homeracker/issues/90)) ([177f039](https://github.com/kellervater/homeracker/commit/177f039537742ff1d3b5d1c8e5d515b257e9047a))
* update camunda/infra-global-github-actions digest to c779482 ([#118](https://github.com/kellervater/homeracker/issues/118)) ([eb8c84a](https://github.com/kellervater/homeracker/commit/eb8c84a869fc55421634b262764fe19a1a8b978b))
* update camunda/infra-global-github-actions digest to dc24d25 ([#101](https://github.com/kellervater/homeracker/issues/101)) ([ed96b2f](https://github.com/kellervater/homeracker/commit/ed96b2f46d456e7557f3029f9a705422820b8a9e))
* update dependency openscad-linux to v2025.11.16.ai29079 ([#69](https://github.com/kellervater/homeracker/issues/69)) ([59a2c75](https://github.com/kellervater/homeracker/commit/59a2c7556230fadb3cc0c7a10dd7f0cdb1304e6c))
* update openscad nightly ([#102](https://github.com/kellervater/homeracker/issues/102)) ([c73dfe2](https://github.com/kellervater/homeracker/commit/c73dfe21c25e03355ae0ae1738f06f9d6bc9206b))
* update openscad nightly ([#116](https://github.com/kellervater/homeracker/issues/116)) ([37a4b3b](https://github.com/kellervater/homeracker/commit/37a4b3ba708977c27d1686f12c27919e1fd64e8e))
* update openscad nightly ([#120](https://github.com/kellervater/homeracker/issues/120)) ([b1bdd37](https://github.com/kellervater/homeracker/commit/b1bdd37f54c2826f462c20e9a5dca382ade903d4))
* update openscad nightly ([#65](https://github.com/kellervater/homeracker/issues/65)) ([12d5c8d](https://github.com/kellervater/homeracker/commit/12d5c8d871aa8107e9f0d8430362669fb43bd931))
* update openscad nightly ([#75](https://github.com/kellervater/homeracker/issues/75)) ([fc58188](https://github.com/kellervater/homeracker/commit/fc58188dab1dafc1f6a7adcc74ffafa78a36ac26))
* update openscad nightly ([#81](https://github.com/kellervater/homeracker/issues/81)) ([c5d0ee0](https://github.com/kellervater/homeracker/commit/c5d0ee0846df4bdd85dc25ae3637f23501bad40e))
* update openscad nightly ([#91](https://github.com/kellervater/homeracker/issues/91)) ([216c977](https://github.com/kellervater/homeracker/commit/216c977d0f947c9dc2abb7e5eb2765e635933172))
* update openscad nightly ([#99](https://github.com/kellervater/homeracker/issues/99)) ([93c34c3](https://github.com/kellervater/homeracker/commit/93c34c3bf19cab309420fe0fa58d264b757aa6ea))
* update pre-commit hook renovatebot/pre-commit-hooks to v42.22.0 ([#93](https://github.com/kellervater/homeracker/issues/93)) ([e572e14](https://github.com/kellervater/homeracker/commit/e572e14659334bd96d5fa1322a3d9a3fd65b2616))
* update pre-commit hook renovatebot/pre-commit-hooks to v42.26.11 ([#100](https://github.com/kellervater/homeracker/issues/100)) ([2b2eead](https://github.com/kellervater/homeracker/commit/2b2eead8c3f2aba8c6995485c9a018f63cd063c1))
* update pre-commit hook renovatebot/pre-commit-hooks to v42.39.2 ([#121](https://github.com/kellervater/homeracker/issues/121)) ([c4c1a02](https://github.com/kellervater/homeracker/commit/c4c1a02a4024196b710d239ed8cc28e5305159ff))
* update pre-commit hooks ([#103](https://github.com/kellervater/homeracker/issues/103)) ([f298ab0](https://github.com/kellervater/homeracker/commit/f298ab0a2a294ef37eee68379df9baf3caf8bc41))
* update pre-commit hooks ([#117](https://github.com/kellervater/homeracker/issues/117)) ([ae3af57](https://github.com/kellervater/homeracker/commit/ae3af5758b774456c3b571452ea686e7b5aaf980))
* update pre-commit hooks ([#83](https://github.com/kellervater/homeracker/issues/83)) ([e41bd82](https://github.com/kellervater/homeracker/commit/e41bd8235f28f4ebf7ce923da1652e11385e2d95))

### 📚 Documentation

* added funding.yml ([cea9391](https://github.com/kellervater/homeracker/commit/cea93915dc2faa03db9c4e3a26de7eed636cfb95))
* added YT video link ([38f6437](https://github.com/kellervater/homeracker/commit/38f64377dfb394c4a7912a995620d31e280d69fc))
* contributing & deprecation ([345ed8a](https://github.com/kellervater/homeracker/commit/345ed8a18c4ab1c53a3f6ee80ef2daebe5f66b1b))
* discord webhook ([#51](https://github.com/kellervater/homeracker/issues/51)) ([6e957d6](https://github.com/kellervater/homeracker/commit/6e957d6411a679418dcb95f3bb7512a3df019cbd))
* fixed links ([9ed1685](https://github.com/kellervater/homeracker/commit/9ed1685b80f1e068c8dfe9ae5dfd8c83e374da05))
* fixes ([f50d771](https://github.com/kellervater/homeracker/commit/f50d771b60d3212fbcaec18018c94a8af583a124))
* **fix:** links in README.md to point to correct repository ([#29](https://github.com/kellervater/homeracker/issues/29)) ([b77c955](https://github.com/kellervater/homeracker/commit/b77c95513228265e55954a4e5adcdf41815d631d))
* Initial Version ([#9](https://github.com/kellervater/homeracker/issues/9)) ([3e935d4](https://github.com/kellervater/homeracker/commit/3e935d4f3da89b842c48c47c9a4f99cbf248f606))
* linux and macos support ([#87](https://github.com/kellervater/homeracker/issues/87)) ([e072ef0](https://github.com/kellervater/homeracker/commit/e072ef0c69105fcb049f200a2db8dd0d1491b5e2))
* **rackmount-ears:** readme and scad comments ([1e7e5d1](https://github.com/kellervater/homeracker/commit/1e7e5d16b66b43d8dde7aeddd37f25daeaae6d29))
* readme ([cbd41b6](https://github.com/kellervater/homeracker/commit/cbd41b65d32c2a2dfd83b495e31181f54ebdec42))
* readme ([bfcfa14](https://github.com/kellervater/homeracker/commit/bfcfa140477c382c4e51d88c089aec0a09d92f90))
* removed todo section ([e557128](https://github.com/kellervater/homeracker/commit/e5571281eb18eb0e9607ffa04117ef473eb13a83))
* setup ([cc66559](https://github.com/kellervater/homeracker/commit/cc665596c48c460a3cd29d6f80fd37bc7f90a023))
* try fixing links once more ([1ad8a68](https://github.com/kellervater/homeracker/commit/1ad8a68308f483edba45a45c40f840f8e05ccc2e))
* updated links & anchors ([44ed174](https://github.com/kellervater/homeracker/commit/44ed1746f911fb73c3233d94e4a6a740c1ca00ab))
* updated ToDos ([9dd9add](https://github.com/kellervater/homeracker/commit/9dd9add8612cc9accdf006acd6b55e1d40d2f241))

### 🔄 CI/CD

* Add CODEOWNERS file for automatic review assignment ([#50](https://github.com/kellervater/homeracker/issues/50)) ([c08b9ee](https://github.com/kellervater/homeracker/commit/c08b9ee32df19a84ad8f866ce1634777f16ac9db))
* added renovate config ([32e99ea](https://github.com/kellervater/homeracker/commit/32e99eae744d1886ac1396ab44f192c57175c8a6))
* auto approve release prs ([#58](https://github.com/kellervater/homeracker/issues/58)) ([f04d780](https://github.com/kellervater/homeracker/commit/f04d780ce0bc361bf4462b56774bca8e9d001204))
* automerge ([3de18db](https://github.com/kellervater/homeracker/commit/3de18db9315e523c4e3435b15c0696696fde840c))
* change changelog-type from 'github' to 'default' ([b523b82](https://github.com/kellervater/homeracker/commit/b523b827129c486e4674dbca5b5d97d720babc43))
* disable platform automerge ([18ed555](https://github.com/kellervater/homeracker/commit/18ed555e943e85c386b1ca9592142202950f29e7))
* don't need explicit renovate annotatation on shellcheck ([78b1b8d](https://github.com/kellervater/homeracker/commit/78b1b8d5ddf366fb811a54c71c4c378958cd3e07))
* improve pre-commit hooks ([#97](https://github.com/kellervater/homeracker/issues/97)) ([b1f416b](https://github.com/kellervater/homeracker/commit/b1f416b59f2acf0366ab6dcb418b651bf3ad7475)), closes [#45](https://github.com/kellervater/homeracker/issues/45)
* linting ([33eb8a8](https://github.com/kellervater/homeracker/commit/33eb8a876f237a67f79016eb1257a00ef25ddeed))
* linting ([eb327aa](https://github.com/kellervater/homeracker/commit/eb327aab0e2c4c52ca9589755d2f1492743b1677))
* **pr titles:** fix validation ([d87e499](https://github.com/kellervater/homeracker/commit/d87e49989c7e607cca449ef6de97a872938cc08c))
* **pre-commit:** enforce conventional commits ([#112](https://github.com/kellervater/homeracker/issues/112)) ([c3ec5ef](https://github.com/kellervater/homeracker/commit/c3ec5ef9a860c5514b654aecda61f1e6bcffad5b))
* remove auto-approval wf ([d8e06f4](https://github.com/kellervater/homeracker/commit/d8e06f4a7de88b69a76c0f1a970f4025318781e2))
* renovate automerge config ([0b003c7](https://github.com/kellervater/homeracker/commit/0b003c772dc051c7beca8444ffd6dc41f9730223))
* renovate config ([8cd9ed9](https://github.com/kellervater/homeracker/commit/8cd9ed9b0a85be073da9f78a1b2cc91fda9bd877))
* renovate regex try [#2](https://github.com/kellervater/homeracker/issues/2) ([2a0be43](https://github.com/kellervater/homeracker/commit/2a0be436dccd6f6c9777d39518e6789147946830))
* **renovate:** activate automerge for openscad ([#64](https://github.com/kellervater/homeracker/issues/64)) ([0f1c11e](https://github.com/kellervater/homeracker/commit/0f1c11e03a4231f9589721e0c321da6783b772e4))
* **renovate:** add BOSL2 to automerge section ([3718452](https://github.com/kellervater/homeracker/commit/3718452d343e32629c4547883f74168e439e620d))
* **renovate:** align release and renovate schedules ([24a1bca](https://github.com/kellervater/homeracker/commit/24a1bca18bbbf5f3e5a053717044925ef9bf3e32))
* **renovate:** allow automerge for actions/chekcout ([7641f1e](https://github.com/kellervater/homeracker/commit/7641f1ecf9fea59b15cf6867f4d73ee21942a22d))
* **renovate:** allow automerge of actions/create-github-app-token ([a78dccc](https://github.com/kellervater/homeracker/commit/a78dccc44ff00342fbc584401eded40f98f084c0))
* **renovate:** allow PRs anytime ([5a7cadc](https://github.com/kellervater/homeracker/commit/5a7cadc4c906025fd93e10ea13241c5d20a6ad39))
* **renovate:** automerge various gha ([#84](https://github.com/kellervater/homeracker/issues/84)) ([cdf34e3](https://github.com/kellervater/homeracker/commit/cdf34e375e46b231dfc2372bd324cbcc579e8688))
* **renovate:** deactivate platform automerge ([50f49ef](https://github.com/kellervater/homeracker/commit/50f49ef8e67f59cfeb19981546bdbf0be3886f43))
* **renovate:** enable weekly schedule ([c47bae8](https://github.com/kellervater/homeracker/commit/c47bae881b82f7125a4eb24e7db1bf252b3f4b79))
* **renovate:** fix BOSL2 upgrades ([#89](https://github.com/kellervater/homeracker/issues/89)) ([a337a17](https://github.com/kellervater/homeracker/commit/a337a17558b8d52e2b4b9271583353860d70bddf))
* **renovate:** fix syntax, change prefixes ([07b4912](https://github.com/kellervater/homeracker/commit/07b4912e9843bc6ee05926d136acf362104876fb))
* **renovate:** group pre-commit PRs ([#79](https://github.com/kellervater/homeracker/issues/79)) ([68d036e](https://github.com/kellervater/homeracker/commit/68d036ee2f3a364ec22ff86fffc18208bfb4fd2c))
* **renovate:** prettify commit prefixes ([cae76bb](https://github.com/kellervater/homeracker/commit/cae76bb4370ba0ef9767d0af0b477900ed491bd3))
* try regex ([6ad1f15](https://github.com/kellervater/homeracker/commit/6ad1f15857f9fb8834463562961d16711de3777f))
* use different automerge approach ([#59](https://github.com/kellervater/homeracker/issues/59)) ([606881f](https://github.com/kellervater/homeracker/commit/606881f599c75a215151c38dd03ac64835b36a7d))

### 🔧 Miscellaneous

* Configure Renovate ([#8](https://github.com/kellervater/homeracker/issues/8)) ([021cf7b](https://github.com/kellervater/homeracker/commit/021cf7b78d996247b72816cb7755976d9fe09b4e))
* **deps:** update openscad nightly to v2025 ([#62](https://github.com/kellervater/homeracker/issues/62)) ([50bbaea](https://github.com/kellervater/homeracker/commit/50bbaea689a928b416e4476f7d3cd80e04a7a873))
* **main:** release 1.0.0 ([#56](https://github.com/kellervater/homeracker/issues/56)) ([14d2ee0](https://github.com/kellervater/homeracker/commit/14d2ee094202f09f6e8dd34d71b6a254593fb4ac))
* **main:** release 1.0.1 ([#61](https://github.com/kellervater/homeracker/issues/61)) ([11cd80c](https://github.com/kellervater/homeracker/commit/11cd80c7bf61c90b91b2aa675d490da10177d49a))
* **main:** release 1.1.0 ([#78](https://github.com/kellervater/homeracker/issues/78)) ([ad04112](https://github.com/kellervater/homeracker/commit/ad04112dd8b4fb5a39e83001ad9d82fcbc6fba88))
* **main:** release 1.2.0 ([#86](https://github.com/kellervater/homeracker/issues/86)) ([c4b2415](https://github.com/kellervater/homeracker/commit/c4b24150d2cc2b3e576f78602f6c2c841deb5ac1))
* pre-commit config for python ([bbb742f](https://github.com/kellervater/homeracker/commit/bbb742f2715971b73f7aa2b9dea373dc17dca6da))
* **renovate:** config hygiene ([e5337de](https://github.com/kellervater/homeracker/commit/e5337de0bea5c011619c1c569b839d8666a785ad))

### ♻️ Code Refactoring

* docs and licenses ([04f76ac](https://github.com/kellervater/homeracker/commit/04f76ace155185b5e926573a58fe708d4f5e5566))
* move rackmount ears ([bee5fd9](https://github.com/kellervater/homeracker/commit/bee5fd99e75c14c8299ee5087e0344766936c3e6))
* renovate and docker ([0b9553a](https://github.com/kellervater/homeracker/commit/0b9553a5953a92bf8fd7abb3af8de36b9cabbffb))
* we obviously don't need this fluff ([c6de162](https://github.com/kellervater/homeracker/commit/c6de16260d0278448bc78731b0ca2e7653ba9d7d))

## [1.2.0](https://github.com/kellervater/homeracker/compare/v1.1.0...v1.2.0) (2025-11-30)

### ✨ Features

* **core:** added more pull-through feet ([#85](https://github.com/kellervater/homeracker/issues/85)) ([d4461c4](https://github.com/kellervater/homeracker/commit/d4461c4f6841d9316901127a4e21240775c7493b))

### 🐛 Bug Fixes

* **renovate:** use currentDigest for BOSL2 ([#92](https://github.com/kellervater/homeracker/issues/92)) ([99704a5](https://github.com/kellervater/homeracker/commit/99704a500f9154ea270552db3b0274999a8649c7))
* **renovate:** use full git URL for BOSL2 automerge matching ([#96](https://github.com/kellervater/homeracker/issues/96)) ([f7997e7](https://github.com/kellervater/homeracker/commit/f7997e7e3ebdff9b82ddae7e91f4955a352c5fb7))

### 📦 Dependencies

* update belfryscad/bosl2 digest to 266792b ([#95](https://github.com/kellervater/homeracker/issues/95)) ([a57d100](https://github.com/kellervater/homeracker/commit/a57d1004ee25e987641de28c9ae30f738933300f))
* update camunda/infra-global-github-actions digest to b0fe528 ([#104](https://github.com/kellervater/homeracker/issues/104)) ([03d3cd6](https://github.com/kellervater/homeracker/commit/03d3cd64df99b8d7470c6d64f297f18d0559d1f6))
* update camunda/infra-global-github-actions digest to b80b223 ([#90](https://github.com/kellervater/homeracker/issues/90)) ([177f039](https://github.com/kellervater/homeracker/commit/177f039537742ff1d3b5d1c8e5d515b257e9047a))
* update camunda/infra-global-github-actions digest to dc24d25 ([#101](https://github.com/kellervater/homeracker/issues/101)) ([ed96b2f](https://github.com/kellervater/homeracker/commit/ed96b2f46d456e7557f3029f9a705422820b8a9e))
* update openscad nightly ([#102](https://github.com/kellervater/homeracker/issues/102)) ([c73dfe2](https://github.com/kellervater/homeracker/commit/c73dfe21c25e03355ae0ae1738f06f9d6bc9206b))
* update openscad nightly ([#91](https://github.com/kellervater/homeracker/issues/91)) ([216c977](https://github.com/kellervater/homeracker/commit/216c977d0f947c9dc2abb7e5eb2765e635933172))
* update openscad nightly ([#99](https://github.com/kellervater/homeracker/issues/99)) ([93c34c3](https://github.com/kellervater/homeracker/commit/93c34c3bf19cab309420fe0fa58d264b757aa6ea))
* update pre-commit hook renovatebot/pre-commit-hooks to v42.22.0 ([#93](https://github.com/kellervater/homeracker/issues/93)) ([e572e14](https://github.com/kellervater/homeracker/commit/e572e14659334bd96d5fa1322a3d9a3fd65b2616))
* update pre-commit hook renovatebot/pre-commit-hooks to v42.26.11 ([#100](https://github.com/kellervater/homeracker/issues/100)) ([2b2eead](https://github.com/kellervater/homeracker/commit/2b2eead8c3f2aba8c6995485c9a018f63cd063c1))
* update pre-commit hooks ([#103](https://github.com/kellervater/homeracker/issues/103)) ([f298ab0](https://github.com/kellervater/homeracker/commit/f298ab0a2a294ef37eee68379df9baf3caf8bc41))

### 📚 Documentation

* contributing & deprecation ([345ed8a](https://github.com/kellervater/homeracker/commit/345ed8a18c4ab1c53a3f6ee80ef2daebe5f66b1b))
* linux and macos support ([#87](https://github.com/kellervater/homeracker/issues/87)) ([e072ef0](https://github.com/kellervater/homeracker/commit/e072ef0c69105fcb049f200a2db8dd0d1491b5e2))

### 🔄 CI/CD

* improve pre-commit hooks ([#97](https://github.com/kellervater/homeracker/issues/97)) ([b1f416b](https://github.com/kellervater/homeracker/commit/b1f416b59f2acf0366ab6dcb418b651bf3ad7475)), closes [#45](https://github.com/kellervater/homeracker/issues/45)
* **renovate:** add BOSL2 to automerge section ([3718452](https://github.com/kellervater/homeracker/commit/3718452d343e32629c4547883f74168e439e620d))
* **renovate:** align release and renovate schedules ([24a1bca](https://github.com/kellervater/homeracker/commit/24a1bca18bbbf5f3e5a053717044925ef9bf3e32))
* **renovate:** allow PRs anytime ([5a7cadc](https://github.com/kellervater/homeracker/commit/5a7cadc4c906025fd93e10ea13241c5d20a6ad39))
* **renovate:** fix BOSL2 upgrades ([#89](https://github.com/kellervater/homeracker/issues/89)) ([a337a17](https://github.com/kellervater/homeracker/commit/a337a17558b8d52e2b4b9271583353860d70bddf))

## [1.1.0](https://github.com/kellervater/homeracker/compare/v1.0.1...v1.1.0) (2025-11-23)

### ✨ Features

* **core:** provide HomeRacker core as OpenSCAD library ([#32](https://github.com/kellervater/homeracker/issues/32)) ([a50e774](https://github.com/kellervater/homeracker/commit/a50e774507f9102238b0d63465a5388bbf876149))

### 📦 Dependencies

* update actions/setup-python action to v6 ([#82](https://github.com/kellervater/homeracker/issues/82)) ([a77c738](https://github.com/kellervater/homeracker/commit/a77c7382471e3549f6b762b6d73b9425de5490c0))
* update camunda/infra-global-github-actions digest to 83dd377 ([#80](https://github.com/kellervater/homeracker/issues/80)) ([3c03342](https://github.com/kellervater/homeracker/commit/3c033423a1ebbcd80f5afd33f7c1e85c1b95b17d))
* update openscad nightly ([#81](https://github.com/kellervater/homeracker/issues/81)) ([c5d0ee0](https://github.com/kellervater/homeracker/commit/c5d0ee0846df4bdd85dc25ae3637f23501bad40e))
* update pre-commit hooks ([#83](https://github.com/kellervater/homeracker/issues/83)) ([e41bd82](https://github.com/kellervater/homeracker/commit/e41bd8235f28f4ebf7ce923da1652e11385e2d95))

### 🔄 CI/CD

* **renovate:** automerge various gha ([#84](https://github.com/kellervater/homeracker/issues/84)) ([cdf34e3](https://github.com/kellervater/homeracker/commit/cdf34e375e46b231dfc2372bd324cbcc579e8688))
* **renovate:** group pre-commit PRs ([#79](https://github.com/kellervater/homeracker/issues/79)) ([68d036e](https://github.com/kellervater/homeracker/commit/68d036ee2f3a364ec22ff86fffc18208bfb4fd2c))

## [1.0.1](https://github.com/kellervater/homeracker/compare/v1.0.0...v1.0.1) (2025-11-21)

### 🐛 Bug Fixes

* **renovate:** openSCAD nightly versions ([#60](https://github.com/kellervater/homeracker/issues/60)) ([5e4e70d](https://github.com/kellervater/homeracker/commit/5e4e70d91e7e57b964c8d32627b85fdfee2a5708))
* **renovate:** preserve .ai suffix for Linux OpenSCAD versions ([#63](https://github.com/kellervater/homeracker/issues/63)) ([a391cd3](https://github.com/kellervater/homeracker/commit/a391cd3bb30043bc8b1c39a97b9f6facc43c3989))

### 📦 Dependencies

* update actions/checkout action to v5 ([#54](https://github.com/kellervater/homeracker/issues/54)) ([405cd76](https://github.com/kellervater/homeracker/commit/405cd76e23cdb7dc2db850533bd16f64f6ff13c2))
* update actions/checkout action to v6 ([#76](https://github.com/kellervater/homeracker/issues/76)) ([82c90c4](https://github.com/kellervater/homeracker/commit/82c90c4fd9ad97d152d13531b9503146d840a4c9))
* update actions/create-github-app-token action to v2 ([#52](https://github.com/kellervater/homeracker/issues/52)) ([536396f](https://github.com/kellervater/homeracker/commit/536396f6a5c69f201b9220aa692426a66365d29a))
* update actions/upload-artifact action to v5 ([#57](https://github.com/kellervater/homeracker/issues/57)) ([c403c66](https://github.com/kellervater/homeracker/commit/c403c66ecd8d381f67c4eac8a29dd8875b5dd30a))
* update camunda/infra-global-github-actions digest to 92fe1f4 ([#74](https://github.com/kellervater/homeracker/issues/74)) ([abd04ce](https://github.com/kellervater/homeracker/commit/abd04ce0516324babc7df387abd06333b7fdf00a))
* update dependency openscad-linux to v2025.11.16.ai29079 ([#69](https://github.com/kellervater/homeracker/issues/69)) ([59a2c75](https://github.com/kellervater/homeracker/commit/59a2c7556230fadb3cc0c7a10dd7f0cdb1304e6c))
* update openscad nightly ([#65](https://github.com/kellervater/homeracker/issues/65)) ([12d5c8d](https://github.com/kellervater/homeracker/commit/12d5c8d871aa8107e9f0d8430362669fb43bd931))
* update openscad nightly ([#75](https://github.com/kellervater/homeracker/issues/75)) ([fc58188](https://github.com/kellervater/homeracker/commit/fc58188dab1dafc1f6a7adcc74ffafa78a36ac26))

### 🔄 CI/CD

* **pr titles:** fix validation ([d87e499](https://github.com/kellervater/homeracker/commit/d87e49989c7e607cca449ef6de97a872938cc08c))
* **renovate:** activate automerge for openscad ([#64](https://github.com/kellervater/homeracker/issues/64)) ([0f1c11e](https://github.com/kellervater/homeracker/commit/0f1c11e03a4231f9589721e0c321da6783b772e4))
* **renovate:** allow automerge for actions/chekcout ([7641f1e](https://github.com/kellervater/homeracker/commit/7641f1ecf9fea59b15cf6867f4d73ee21942a22d))
* **renovate:** allow automerge of actions/create-github-app-token ([a78dccc](https://github.com/kellervater/homeracker/commit/a78dccc44ff00342fbc584401eded40f98f084c0))
* **renovate:** deactivate platform automerge ([50f49ef](https://github.com/kellervater/homeracker/commit/50f49ef8e67f59cfeb19981546bdbf0be3886f43))
* **renovate:** enable weekly schedule ([c47bae8](https://github.com/kellervater/homeracker/commit/c47bae881b82f7125a4eb24e7db1bf252b3f4b79))
* **renovate:** prettify commit prefixes ([cae76bb](https://github.com/kellervater/homeracker/commit/cae76bb4370ba0ef9767d0af0b477900ed491bd3))

### 🔧 Miscellaneous

* **deps:** update openscad nightly to v2025 ([#62](https://github.com/kellervater/homeracker/issues/62)) ([50bbaea](https://github.com/kellervater/homeracker/commit/50bbaea689a928b416e4476f7d3cd80e04a7a873))
* **renovate:** config hygiene ([e5337de](https://github.com/kellervater/homeracker/commit/e5337de0bea5c011619c1c569b839d8666a785ad))

## 1.0.0 (2025-11-15)

### ✨ Features

* add overlay logo ([3a7f1eb](https://github.com/kellervater/homeracker/commit/3a7f1ebb1b8021bae5df22993788e84048828501))
* add ruby & intentionally downgrade versions ([9fe7a61](https://github.com/kellervater/homeracker/commit/9fe7a614172d33807ef0971de4f9d8fdc9d4f5f2))
* added license ([f022f04](https://github.com/kellervater/homeracker/commit/f022f047a8f26d04f4f4ff772501f41631d5040d))
* asdf installation ([2b9e906](https://github.com/kellervater/homeracker/commit/2b9e906e72e55ded040e7ba683f0f8dca2a4183c))
* bunch of raw data ([7b4590c](https://github.com/kellervater/homeracker/commit/7b4590c2de6d188a7fb4a3c5e9acf51fd706d44f))
* **ci:** add CI workflow to validate OpenSCAD model rendering ([#48](https://github.com/kellervater/homeracker/issues/48)) ([030e5ca](https://github.com/kellervater/homeracker/commit/030e5ca20ddf464dca76964dd9a082dcf9eac60e))
* **copilot:** added 1st instruction draft ([d9eac22](https://github.com/kellervater/homeracker/commit/d9eac222e419163c7d192041336d1bdf5033aa0c))
* core export script ([27213d9](https://github.com/kellervater/homeracker/commit/27213d9d50b7af9723158aff833b2ee3181a218e))
* favicon ([e91dffa](https://github.com/kellervater/homeracker/commit/e91dffa6cc961de2977d045494f1ce6477faed0a))
* flexmount bracket ([98e19ef](https://github.com/kellervater/homeracker/commit/98e19efa60837c36e77f0a96e2a7099e3447ec06))
* gridfinity baseplate ([4c7c8f2](https://github.com/kellervater/homeracker/commit/4c7c8f2dc3b2ea4e46e975c161c5cbda4e3c0698))
* implement automated releases with Camunda GitHub actions ([#49](https://github.com/kellervater/homeracker/issues/49)) ([62691cb](https://github.com/kellervater/homeracker/commit/62691cb3bbf69b4f0de370c3fbd6fbd1b0859674))
* jpg to png to svg ([099b754](https://github.com/kellervater/homeracker/commit/099b754156948867b8e0ea572d85e2b45482394e))
* **rackmount_ears:** asymetry slider ([#13](https://github.com/kellervater/homeracker/issues/13)) ([ebeb258](https://github.com/kellervater/homeracker/commit/ebeb258d60adb0c36ee70117b69d417d8d49e0e4))
* **rackmount_ears:** option to show actual ear distance ([beb5f39](https://github.com/kellervater/homeracker/commit/beb5f39722bc5680f79e917926e8de0b1e80e40d))
* **rackmount-ears:** initial commit ([482484c](https://github.com/kellervater/homeracker/commit/482484cb8316df7ecc114230172e613bbe0bd46e))
* scad installer ([#41](https://github.com/kellervater/homeracker/issues/41)) ([688d7a3](https://github.com/kellervater/homeracker/commit/688d7a3535459f923bc4d0471bade288b184d1d1))
* set theme ([d80e7ee](https://github.com/kellervater/homeracker/commit/d80e7ee17e425d45652ccebd67f3e2bf997169a2))
* **shelf:** python exporter ([a5bad40](https://github.com/kellervater/homeracker/commit/a5bad400827f257ce0c43e125242ff8274f4074b))
* wallmount ([#14](https://github.com/kellervater/homeracker/issues/14)) ([a1c8d11](https://github.com/kellervater/homeracker/commit/a1c8d11b6afb284a4d9c5a9db20a4ae25d2b3b18))

### 🐛 Bug Fixes

* **ci:** release please config ([#55](https://github.com/kellervater/homeracker/issues/55)) ([9c95988](https://github.com/kellervater/homeracker/commit/9c9598895b12ca43cc1b1610b7ca83af67040708))
* emojis ([35f0caa](https://github.com/kellervater/homeracker/commit/35f0caa9d1c8654bf940bb42eefeaca432976d93))
* favicon ([91a43c8](https://github.com/kellervater/homeracker/commit/91a43c8259ecb59a6d87839654a0f5d72916a3ed))
* logo details ([34cd659](https://github.com/kellervater/homeracker/commit/34cd65917727176b8c6228104c2c1941341a05a1))
* logo transparency ([bc80d1e](https://github.com/kellervater/homeracker/commit/bc80d1e65f0a208370250984faaf87915f97c45f))
* makerworld link ([c4bc57d](https://github.com/kellervater/homeracker/commit/c4bc57de6d306e34419b8ad39d661ec4cebbcf68))
* move release-please config files to .github/config ([#53](https://github.com/kellervater/homeracker/issues/53)) ([5a423bc](https://github.com/kellervater/homeracker/commit/5a423bc23380d0bffe726a24429819f817186d52))
* **rackmountears:** sane defaults ([a1a6777](https://github.com/kellervater/homeracker/commit/a1a6777aea8052ad672fe6c37afcb5b9a0a13646))
* transparent favicon ([631ef6e](https://github.com/kellervater/homeracker/commit/631ef6e837eb892209c4c0c188415f29fadf875d))
* **unimount:** typo ([b5508af](https://github.com/kellervater/homeracker/commit/b5508af9d36289f1452a2cb9a734a6c1ec12f7d5))

### 📚 Documentation

* added funding.yml ([cea9391](https://github.com/kellervater/homeracker/commit/cea93915dc2faa03db9c4e3a26de7eed636cfb95))
* added YT video link ([38f6437](https://github.com/kellervater/homeracker/commit/38f64377dfb394c4a7912a995620d31e280d69fc))
* discord webhook ([#51](https://github.com/kellervater/homeracker/issues/51)) ([6e957d6](https://github.com/kellervater/homeracker/commit/6e957d6411a679418dcb95f3bb7512a3df019cbd))
* fixed links ([9ed1685](https://github.com/kellervater/homeracker/commit/9ed1685b80f1e068c8dfe9ae5dfd8c83e374da05))
* fixes ([f50d771](https://github.com/kellervater/homeracker/commit/f50d771b60d3212fbcaec18018c94a8af583a124))
* **fix:** links in README.md to point to correct repository ([#29](https://github.com/kellervater/homeracker/issues/29)) ([b77c955](https://github.com/kellervater/homeracker/commit/b77c95513228265e55954a4e5adcdf41815d631d))
* Initial Version ([#9](https://github.com/kellervater/homeracker/issues/9)) ([3e935d4](https://github.com/kellervater/homeracker/commit/3e935d4f3da89b842c48c47c9a4f99cbf248f606))
* **rackmount-ears:** readme and scad comments ([1e7e5d1](https://github.com/kellervater/homeracker/commit/1e7e5d16b66b43d8dde7aeddd37f25daeaae6d29))
* readme ([cbd41b6](https://github.com/kellervater/homeracker/commit/cbd41b65d32c2a2dfd83b495e31181f54ebdec42))
* readme ([bfcfa14](https://github.com/kellervater/homeracker/commit/bfcfa140477c382c4e51d88c089aec0a09d92f90))
* removed todo section ([e557128](https://github.com/kellervater/homeracker/commit/e5571281eb18eb0e9607ffa04117ef473eb13a83))
* setup ([cc66559](https://github.com/kellervater/homeracker/commit/cc665596c48c460a3cd29d6f80fd37bc7f90a023))
* try fixing links once more ([1ad8a68](https://github.com/kellervater/homeracker/commit/1ad8a68308f483edba45a45c40f840f8e05ccc2e))
* updated links & anchors ([44ed174](https://github.com/kellervater/homeracker/commit/44ed1746f911fb73c3233d94e4a6a740c1ca00ab))
* updated ToDos ([9dd9add](https://github.com/kellervater/homeracker/commit/9dd9add8612cc9accdf006acd6b55e1d40d2f241))

### 🔄 CI/CD

* Add CODEOWNERS file for automatic review assignment ([#50](https://github.com/kellervater/homeracker/issues/50)) ([c08b9ee](https://github.com/kellervater/homeracker/commit/c08b9ee32df19a84ad8f866ce1634777f16ac9db))
* added renovate config ([32e99ea](https://github.com/kellervater/homeracker/commit/32e99eae744d1886ac1396ab44f192c57175c8a6))
* auto approve release prs ([#58](https://github.com/kellervater/homeracker/issues/58)) ([f04d780](https://github.com/kellervater/homeracker/commit/f04d780ce0bc361bf4462b56774bca8e9d001204))
* automerge ([3de18db](https://github.com/kellervater/homeracker/commit/3de18db9315e523c4e3435b15c0696696fde840c))
* change changelog-type from 'github' to 'default' ([b523b82](https://github.com/kellervater/homeracker/commit/b523b827129c486e4674dbca5b5d97d720babc43))
* disable platform automerge ([18ed555](https://github.com/kellervater/homeracker/commit/18ed555e943e85c386b1ca9592142202950f29e7))
* don't need explicit renovate annotatation on shellcheck ([78b1b8d](https://github.com/kellervater/homeracker/commit/78b1b8d5ddf366fb811a54c71c4c378958cd3e07))
* linting ([33eb8a8](https://github.com/kellervater/homeracker/commit/33eb8a876f237a67f79016eb1257a00ef25ddeed))
* linting ([eb327aa](https://github.com/kellervater/homeracker/commit/eb327aab0e2c4c52ca9589755d2f1492743b1677))
* remove auto-approval wf ([d8e06f4](https://github.com/kellervater/homeracker/commit/d8e06f4a7de88b69a76c0f1a970f4025318781e2))
* renovate automerge config ([0b003c7](https://github.com/kellervater/homeracker/commit/0b003c772dc051c7beca8444ffd6dc41f9730223))
* renovate config ([8cd9ed9](https://github.com/kellervater/homeracker/commit/8cd9ed9b0a85be073da9f78a1b2cc91fda9bd877))
* renovate regex try [#2](https://github.com/kellervater/homeracker/issues/2) ([2a0be43](https://github.com/kellervater/homeracker/commit/2a0be436dccd6f6c9777d39518e6789147946830))
* **renovate:** fix syntax, change prefixes ([07b4912](https://github.com/kellervater/homeracker/commit/07b4912e9843bc6ee05926d136acf362104876fb))
* try regex ([6ad1f15](https://github.com/kellervater/homeracker/commit/6ad1f15857f9fb8834463562961d16711de3777f))
* use different automerge approach ([#59](https://github.com/kellervater/homeracker/issues/59)) ([606881f](https://github.com/kellervater/homeracker/commit/606881f599c75a215151c38dd03ac64835b36a7d))

### 🔧 Miscellaneous

* Configure Renovate ([#8](https://github.com/kellervater/homeracker/issues/8)) ([021cf7b](https://github.com/kellervater/homeracker/commit/021cf7b78d996247b72816cb7755976d9fe09b4e))
* pre-commit config for python ([bbb742f](https://github.com/kellervater/homeracker/commit/bbb742f2715971b73f7aa2b9dea373dc17dca6da))

### ♻️ Code Refactoring

* docs and licenses ([04f76ac](https://github.com/kellervater/homeracker/commit/04f76ace155185b5e926573a58fe708d4f5e5566))
* move rackmount ears ([bee5fd9](https://github.com/kellervater/homeracker/commit/bee5fd99e75c14c8299ee5087e0344766936c3e6))
* renovate and docker ([0b9553a](https://github.com/kellervater/homeracker/commit/0b9553a5953a92bf8fd7abb3af8de36b9cabbffb))
* we obviously don't need this fluff ([c6de162](https://github.com/kellervater/homeracker/commit/c6de16260d0278448bc78731b0ca2e7653ba9d7d))

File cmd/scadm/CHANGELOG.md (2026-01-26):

# Changelog

## [0.4.5](https://github.com/kellerlabs/homeracker/compare/scadm-v0.4.4...scadm-v0.4.5) (2026-01-25)

### 📦 Dependencies

* update dependency openscad-windows to v2026.01.19 ([#210](https://github.com/kellerlabs/homeracker/issues/210)) ([c57df5a](https://github.com/kellerlabs/homeracker/commit/c57df5adcf7967cf6e21b5fa8d622673bd7fc38e))
* update dependency openscad-windows to v2026.01.25 ([#211](https://github.com/kellerlabs/homeracker/issues/211)) ([e4f6407](https://github.com/kellerlabs/homeracker/commit/e4f640767a17eba1c7e8dd5efc208515cc1b47cf))

## [0.4.4](https://github.com/kellerlabs/homeracker/compare/scadm-v0.4.3...scadm-v0.4.4) (2026-01-18)

### 📦 Dependencies

* update dependency openscad-windows to v2026.01.18 ([#202](https://github.com/kellerlabs/homeracker/issues/202)) ([b7098c9](https://github.com/kellerlabs/homeracker/commit/b7098c985831d87701509cb4d5e29b9e9f194405))

### ♻️ Code Refactoring

* update repository references from kellervater to kellerlabs ([#198](https://github.com/kellerlabs/homeracker/issues/198)) ([8e5717b](https://github.com/kellerlabs/homeracker/commit/8e5717bf0ee1b8b2e06d247fccb83eced79f06ee))

## [0.4.3](https://github.com/kellervater/homeracker/compare/scadm-v0.4.2...scadm-v0.4.3) (2026-01-04)

### 📦 Dependencies

* update dependency openscad-windows to v2026.01.03 ([#186](https://github.com/kellervater/homeracker/issues/186)) ([fce4a5a](https://github.com/kellervater/homeracker/commit/fce4a5ae4af4324405e63a119a5204fa941819ac))
* update openscad nightly to v2026 ([#182](https://github.com/kellervater/homeracker/issues/182)) ([45efd5c](https://github.com/kellervater/homeracker/commit/45efd5c58e53859d94c5af7bfe08a8f8bc75003e))

## [0.4.2](https://github.com/kellervater/homeracker/compare/scadm-v0.4.1...scadm-v0.4.2) (2025-12-28)

### 📦 Dependencies

* update openscad nightly ([#165](https://github.com/kellervater/homeracker/issues/165)) ([7f8746c](https://github.com/kellervater/homeracker/commit/7f8746c1c923934d4e4eec0a87b140849aa55919))
* update openscad nightly ([#168](https://github.com/kellervater/homeracker/issues/168)) ([fe441bd](https://github.com/kellervater/homeracker/commit/fe441bd91f4019676d52981e70cb88ca8a09ca56))
* update openscad nightly ([#171](https://github.com/kellervater/homeracker/issues/171)) ([fccf876](https://github.com/kellervater/homeracker/commit/fccf87602d08aef6c9aa0ea41d6ad1353ca9eb93))

## [0.4.1](https://github.com/kellervater/homeracker/compare/scadm-v0.4.0...scadm-v0.4.1) (2025-12-20)

### 📦 Dependencies

* update openscad nightly ([#161](https://github.com/kellervater/homeracker/issues/161)) ([c22aa62](https://github.com/kellervater/homeracker/commit/c22aa62536b6664a6aa112ac5424bc39b5593163))

## [0.4.0](https://github.com/kellervater/homeracker/compare/scadm-v0.3.0...scadm-v0.4.0) (2025-12-15)

### ✨ Features

* **scadm:** add --version flag ([#140](https://github.com/kellervater/homeracker/issues/140)) ([5a7d98c](https://github.com/kellervater/homeracker/commit/5a7d98cfd33c36f9d6e1df95181c42c5c6195b2f))

### 📦 Dependencies

* update openscad nightly ([#148](https://github.com/kellervater/homeracker/issues/148)) ([29756dd](https://github.com/kellervater/homeracker/commit/29756ddfd902c61add8094f56d17e8b709789eda))

## [0.3.0](https://github.com/kellervater/homeracker/compare/scadm-v0.2.1...scadm-v0.3.0) (2025-12-08)

### ✨ Features

* **scadm:** add Python extension support to vscode command ([#133](https://github.com/kellervater/homeracker/issues/133)) ([0bee683](https://github.com/kellervater/homeracker/commit/0bee683232593428290fe116fd7af9ce2c732816))
* **scadm:** add vscode command for extension management ([#131](https://github.com/kellervater/homeracker/issues/131)) ([573c9dd](https://github.com/kellervater/homeracker/commit/573c9ddbbe420c0bd4f1631e240a54e9bac5d5d3))

## [0.2.1](https://github.com/kellervater/homeracker/compare/scadm-v0.2.0...scadm-v0.2.1) (2025-12-07)

### 📦 Dependencies

* update openscad nightly ([#124](https://github.com/kellervater/homeracker/issues/124)) ([b12fc92](https://github.com/kellervater/homeracker/commit/b12fc92673c85ecd519e5875aed2c68d55a3a2ad))

## [0.2.0](https://github.com/kellervater/homeracker/compare/scadm-v0.1.0...scadm-v0.2.0) (2025-12-07)

### ✨ Features

* implement custom dependency manager and renovate preset ([#106](https://github.com/kellervater/homeracker/issues/106)) ([96393d1](https://github.com/kellervater/homeracker/commit/96393d1e91c657abbbfc03465e0c089080300346))

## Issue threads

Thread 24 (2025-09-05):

Spec: Gridfinity Baseplate Outline

kellervater, 2025-09-05:
# Gridfinity Baseplate Specification Outline

## 1. Grid System
- Module pitch: **42.0 mm** (center-to-center)
- Overall size: `(cols * 42.0) + 2 * perimeter_margin`
- Recommended perimeter margin: **2.0–3.0 mm** each side
- Flatness target: warp < **0.5 mm** over any 5×5 cell area

## 2. Cell Pocket Geometry
| Feature | Nominal | Notes |
|---------|---------|-------|
| Pocket opening (top) | 39.2–39.3 mm square | Provides ~1.4–1.5 mm wall + clearance (PLA) |
| Pocket depth | 7.0 mm | Standard depth |
| Base (floor) thickness | 1.6–2.0 mm | >= 5 perimeters (0.4 nozzle) |
| Internal vertical edge fillet | 0.4–0.6 mm | Print quality & stress reduction |
| Top edge chamfer/fillet | 0.6–0.8 mm | Easier insertion |
| XY clearance tuning | +0.15–0.25 mm | Adjust per material |

## 3. Magnet Retention (Optional)
- Magnet: **Ø6 × 3 mm** Neodymium (N35+)
- Hole center offset from cell corner: **9.0–9.2 mm** along X & Y
- Hole diameter: PLA 6.05–6.10 mm; PETG/ABS 6.10–6.20 mm
- Hole depth: 3.10–3.20 mm (leave 0.2–0.3 mm floor)
- Variant: pilot dimple only (user drills / omits magnets)

## 4. Screw Mounts (Optional)
- Pattern: every 2 cells (84 mm pitch) or perimeter-only ~120–160 mm spacing
- Clearance hole (M3): Ø3.2–3.4 mm; countersink 90° × 6.0–6.4 mm
- Boss diameter: 8–9 mm; boss reinforcement +1.0 mm local thickness

## 5. Perimeter & Ribbing
- Perimeter wall thickness: **3.0 mm** (≈2× pocket wall)
- Large plate stiffening (>6×6 cells): underside ribs 1.5–2.0 mm thick, 8–10 mm tall every 2 cells (avoid magnet holes)

## 6. Z Heights (Reference Model Convention)
| Element | Z (relative) |
|---------|--------------|
| Top surface | 0.0 |
| Pocket floor | -7.0 mm |
| Magnet floor (if cut downward) | -5.2 mm (for 1.8 mm base) |

(Adjust sign if modeling base on build plate with positive extrusions.)

## 7. Tolerances & Fits
- Global X/Y compensation: slicer horizontal expansion or built-in oversize +0.15–0.25 mm
- Z tolerance: ±0.1 mm acceptable
- Flatness control: brim, adaptive bed mesh, or corner mouse-ears (Ø6–8 mm × 0.3 mm high)
- Test print a 1×2 cell coupon first

## 8. Print Recommendations
| Setting | Value / Guidance |
|---------|------------------|
| Orientation | Flat, top up |
| Layer height | 0.20 mm (first 0.25) |
| Perimeters | 4–5 |
| Infill | 15–25% grid / gyroid |
| Material | PLA (dim accuracy) / PETG (heat) / ABS+ (enclosure) |
| Cooling | Moderate; ramp to avoid edge lift |
| Adhesion | Brim (2–4 mm) for >5×5 plates |

## 9. Parametric Variables (Suggested Names)
```
cell_cols, cell_rows
unit_pitch = 42.0
pocket_open = 39.2      # or 39.3
pocket_depth = 7.0
base_thickness = 2.0
magnet_dia = 6.1
magnet_depth = 3.15
magnet_offset = 9.1
perimeter_margin = 2.5
wall_thickness = 1.5
chamfer_top = 0.7
```

## 10. CAD Modeling Steps (High-Level)
1. Sketch master grid with construction lines at 42 mm pitch.
2. Sketch pocket square (pocket_open) centered per cell.
3. Extrude base + pocket depth; cut pockets leaving base_thickness.
4. Apply top chamfer/fillet, internal edge fillets.
5. Add magnet hole pattern (offset coordinates); cut to magnet_depth.
6. Create perimeter offset by perimeter_margin.
7. Add screw bosses & countersinks (optional).
8. Add underside ribs if large plate.
9. Apply external edge fillets 0.6–1.0 mm.
10. Emboss indices or logo (optional).

## 11. Large Plate Segmentation (>8×8)
- Split into interlocking dovetail or puzzle joints every 4 cells
- Dovetail: 3 mm depth, 0.15 mm per-side clearance
- Provide alignment chamfer 0.5 mm

## 12. Validation Checklist
- Pocket diagonal: pocket_open * √2 meets expected clearance.
- Test coupon fit with typical container bottom geometry.
- Magnet polarity reference marked (emboss corner).
- Confirm screw boss clearance in slicer preview.
- Check warp risk (simulate shrink or slice preview for bridging).

## 13. Optional Enhancements
- Row/column indices (raised 0.4 mm).
- Cable tie slots in perimeter (6×2 mm).
- Anti-slide pad recesses (8×1 mm underside corners).
- Integrated label frames or NFC tag pocket.
- Variant: thin travel plate (pocket_depth 4 mm) for low profile.

## 14. Material Notes
| Material | Adjustments |
|----------|-------------|
| PLA | Baseline dimensions |
| PETG | Increase XY clearance +0.05 mm; magnets looser |
| ABS/ASA | Enclosure recommended; increase perimeter shells to 6 for stiffness |
| PLA+ CF | Watch abrasive wear; reduce infill to maintain compliance |

## 15. Licensing & Attribution (Placeholder)
Add chosen open hardware license (e.g., CERN-OHL-S) + attribution text here.

---
**Next Steps**: Parametric script (OpenSCAD / Fusion timeline) + 1×2 test coupon variant.
Issue created to track design finalization.

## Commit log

2025-03-27 feat(rackmount-ears): initial commit
    [rackmount_ears.scad]
2025-03-28 docs(rackmount-ears): readme and scad comments
    [rackmount_ears.scad]
2025-04-09 refactor: move rackmount ears
    [rackmount_ears.scad]
2025-04-09 refactor: docs and licenses
    [rackmount_ears.scad]
2025-04-10 ci: linting
    [rackmount_ears.scad]
2025-04-27 feat: flexmount bracket
    [flexmount.scad]
2025-04-27 feat(rackmount_ears): asymetry slider (#13)
    Added "insane" asymetry slider to create differently sized rackmount
    ears.
    [rackmount_ears.scad]
2025-04-27 fix(rackmountears): sane defaults
    [rackmount_ears.scad]
2025-04-27 feat(rackmount_ears): option to show actual ear distance
    [rackmount_ears.scad]
2025-04-27 fix(unimount): typo
    [flexmount.scad]
2025-05-06 feat: wallmount (#14)
    ## 🧰 Wallmount for HomeRacker
    A new utility for your modular setup!
    With this accessory, you can mount a HomeRacker frame to a wall, the
    floor — or even the ceiling if you're feeling adventurous.
    ### 🔧 Customizable Bore Holes
    You can choose between:
    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
    [wallmount.scad]
2025-05-18 feat: gridfinity baseplate
    [base.scad]
2025-08-24 chore: Configure Renovate (#8)
    Welcome to [Renovate](https://redirect.github.com/renovatebot/renovate)!
    This is an onboarding PR to help you understand and configure settings
    before regular Pull Requests begin.
    🚦 To activate Renovate, merge this Pull Request. To disable Renovate,
    simply close this Pull Request unmerged.
    ---
    ### Configuration Summary
    Based on the default config's presets, Renovate will:
    - Start dependency updates only once this onboarding PR is merged
    - Hopefully safe environment variables to allow users to configure.
    - Show all Merge Confidence badges for pull requests.
    - Enable Renovate Dependency Dashboard creation.
    - Use semantic commit type `fix` for de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
2025-09-15 feat: jpg to png to svg
    [png_creation.scad]
2025-11-15 fix(renovate): preserve .ai suffix for Linux OpenSCAD versions (#63)
    ## Problem
    PR #62 showed that Linux OpenSCAD versions were losing the `.ai` suffix:
    - ❌ Linux: `2024.11.18.ai21237` → `2025.11.10` (lost `.ai21237`)
    - ✅ Windows: `2024.11.18` → `2025.11.10` (correct)
    ## Root Cause
    Single `customManager` with one `extractVersionTemplate` caused both
    Windows and Linux variables to receive the same new version from
    datasource (Windows format without `.ai`).
    ## Solution
    Split into **two separate customManagers**:
    - **Windows manager**: `depNameTemplate="OpenSCAD-Windows"`, extracts
    from `.zip` filenames
    - **Linux manager**: `depNameTemplate="OpenSCAD-Linux"`, extracts from
    `.AppIma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
2025-11-15 chore(deps): update openscad nightly to v2025 (#62)
    This PR contains the following updates:
    | Package | Update | Change |
    |---|---|---|
    | OpenSCAD-Linux | major | `2024.11.18.ai21237` -> `2025.11.10.ai28923`
    |
    | OpenSCAD-Windows | major | `2024.11.18` -> `2025.11.10` |
    ### Configuration
    📅 **Schedule**: Branch creation - At any time (no schedule defined),
    Automerge - At any time (no schedule defined).
    🚦 **Automerge**: Enabled.
    ♻ **Rebasing**: Whenever PR is behind base branch, or you tick the
    rebase/retry checkbox.
    🔕 **Ignore**: Close this PR and you won't be reminded about these
    updates again.
    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
2025-11-15 deps: update actions/checkout action to v5 (#54)
    | Package | Type | Update | Change |
    |---|---|---|---|
    | [actions/checkout](https://redirect.github.com/actions/checkout) |
    action | major | `v4` -> `v5` |
    ### Release Notes
    <details>
    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
2025-11-15 deps: update actions/upload-artifact action to v5 (#57)
    [actions/upload-artifact](https://redirect.github.com/actions/upload-artifact)
    | action | major | `v4` -> `v5` |
    <summary>actions/upload-artifact (actions/upload-artifact)</summary>
    ###
    [`v5`](https://redirect.github.com/actions/upload-artifact/compare/v4...v5)
    [Compare
    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
2025-11-16 deps: update openscad nightly (#65)
    | OpenSCAD-Linux | patch | `2025.11.10.ai28923` -> `2025.11.16.ai29065`
    | OpenSCAD-Windows | patch | `2025.11.10` -> `2025.11.16` |
    👻 **Immortal**: This PR will be recreated if closed unmerged. Get
    [config
    help](https://redirect.github.com/renovatebot/renovate/discussions) if
    that's undesired.
    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
2025-11-17 deps: update dependency openscad-linux to v2025.11.16.ai29079 (#69)
    | OpenSCAD-Linux | patch | `2025.11.16.ai29065` -> `2025.11.16.ai29079`
    📅 **Schedule**: Branch creation - "on Friday" (UTC), Automerge - At any
    time (no schedule defined).
    🔕 **Ignore**: Close this PR and you won't be reminded about this update
    again.
    - [ ] <!-- rebase-check -->If you want to rebase/retry this PR, check
    this box
    This PR was generated by [Mend Renovate](https:/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
2025-11-21 deps: update openscad nightly (#75)
    | OpenSCAD-Linux | patch | `2025.11.16.ai29079` -> `2025.11.20.ai29236`
    | OpenSCAD-Windows | patch | `2025.11.16` -> `2025.11.20` |
    - [ ] <!-- rebase-che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
2025-11-21 deps: update camunda/infra-global-github-actions digest to 92fe1f4 (#74)
    | camunda/infra-global-github-actions | action | digest | `1c6cd77` ->
    `92fe1f4` |
    🚦 **Automerge**: Disabled by config. Please merge this manually once you
    are satisfied.
    ♻ **Rebasing**: Whenever PR becomes conflicted, or you tick the
    - [ ] <!-- rebase-check -->If you want to rebase/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
2025-11-21 deps: update actions/checkout action to v6 (#76)
    action | major | `v5` -> `v6` |
    <summary>actions/checkout (actions/checkout)</summary>
    ### [`v6`](https://redirect.github.com/actions/checkout/compare/v5...v6)
    Source](https://redirect.github.com/actions/checkout/compare/v5...v6)
    </details>
    ♻ **Rebasing**: Whenever PR is behind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
2025-11-22 chore(main): release 1.0.1 (#61)
    :robot: I have created a release *beep* *boop*
    ##
    [1.0.1](https://github.com/kellervater/homeracker/compare/v1.0.0...v1.0.1)
    (2025-11-21)
    ### 🐛 Bug Fixes
    * **renovate:** openSCAD nightly versions
    ([#60](https://github.com/kellervater/homeracker/issues/60))
    ([5e4e70d](https://github.com/kellervater/homeracker/commit/5e4e70d91e7e57b964c8d32627b85fdfee2a5708))
    * **renovate:** preserve .ai suffix for Linux OpenSCAD versions
    ([#63](https://github.com/kellervater/homeracker/issues/63))
    ([a391cd3](https://github.com/kellervater/homeracker/commit/a391cd3bb30043bc8b1c39a97b9f6facc43c3989))
    ### 📦 Dependencies
    * update actions/checkout action to v5
    ([#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
2025-11-23 feat(core): provide HomeRacker core as OpenSCAD library (#32)
    📚 **Library Structure**
    • Created main library entry point (`homeracker.scad`) for core components
    • Established modular structure: `core/lib/`, `core/parts/`, `core/presets/`
    • Added complete MIT license headers to all library files
    🔧 **Core Components**
    • **Support**: Parametric beams with lock pin holes, x-holes option
    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
    [base.scad, connector.scad, connectors.scad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]
2025-11-23 ci(renovate): group pre-commit PRs (#79)
    * Adapts the renovate config to group all pre-commit related PRs
    * Enables automerge on them
    * Introduces small documentation on local renovate testing flow
2025-11-23 deps: update openscad nightly (#81)
    | OpenSCAD-Linux | patch | `2025.11.20.ai29236` -> `2025.11.22.ai29346`
    | OpenSCAD-Windows | patch | `2025.11.20` -> `2025.11.22` |
    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
2025-11-23 deps: update camunda/infra-global-github-actions digest to 83dd377 (#80)
    | camunda/infra-global-github-actions | action | digest | `92fe1f4` ->
    `83dd377` |
    This PR was generated b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
2025-11-23 deps: update actions/setup-python action to v6 (#82)
    [actions/setup-python](https://redirect.github.com/actions/setup-python)
    | action | major | `v5` -> `v6` |
    <summary>actions/setup-python (actions/setup-python)</summary>
    [`v6`](https://redirect.github.com/actions/setup-python/compare/v5...v6)
    Source](https://redirect.github.com/actions/setup-python/compare/v5...v6)
    ♻ **Rebas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
2025-11-23 chore(main): release 1.1.0 (#78)
    [1.1.0](https://github.com/kellervater/homeracker/compare/v1.0.1...v1.1.0)
    (2025-11-23)
    ### ✨ Features
    * **core:** provide HomeRacker core as OpenSCAD library
    ([#32](https://github.com/kellervater/homeracker/issues/32))
    ([a50e774](https://github.com/kellervater/homeracker/commit/a50e774507f9102238b0d63465a5388bbf876149))
    * update actions/setup-python action to v6
    ([#82](https://github.com/kellervater/homeracker/issues/82))
    ([a77c738](https://github.com/kellervater/homeracker/commit/a77c7382471e3549f6b762b6d73b9425de5490c0))
    * update camunda/infra-global-github-actions digest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
2025-11-23 feat(core): added more pull-through feet (#85)
    The connector preset (pull-through feet) got 2 new ones:
    * 3D3WFPy -> pull-through y-axis (additionally to x-axis
    * 3D4WFPy -> pull-through y-axis (additionally to x-axis
    We need these both additional ones, since the foot creates an asymetry one doesn't have on regular pull-through connectors
    [connectors.scad]
2025-11-26 deps: update camunda/infra-global-github-actions digest to b80b223 (#90)
    | camunda/infra-global-github-actions | action | digest | `83dd377` ->
    `b80b223` |
    This PR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
2025-11-26 deps: update openscad nightly (#91)
    | OpenSCAD-Linux | patch | `2025.11.22.ai29346` -> `2025.11.24.ai29406`
    | OpenSCAD-Windows | patch | `2025.11.22` -> `2025.11.24` |
    - [ ]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
2025-11-26 fix(renovate): use currentDigest for BOSL2 (#92)
    Fixes a bug in version discovery of BOSL2 dependencies.
    ---------
2025-11-26 docs: linux and macos support (#87)
    Scripts claimed Windows-only support but Linux was already implemented.
    macOS was missing—platform detection fell through to "unknown".
    ## Changes
    ### Platform Detection
    - Added `Darwin*)` case to all installation/test scripts
    - Scripts now detect Windows (CYGWIN/MINGW/MSYS), Linux, and macOS
    - **macOS is treated as Linux** - uses same Linux installation path
    (AppImage)
    ### Implementation Approach
    - **Simplified**: macOS (Darwin) detected but mapped to `"linux"`
    platform
    - **No macOS-specific code**: Uses existing Linux installation logic
    - **Documented as untested**: No macOS test environment available
    - Scripts updated: `cmd/setup/install-openscad.s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
2025-11-26 deps: update belfryscad/bosl2 digest to 266792b (#95)
    | BelfrySCAD/BOSL2 | digest | `088d17d` -> `266792b` |
    📅 **Schedule**: Branch creation - Only on Sunday and Saturday ( * * * *
    0,6 ) (UTC), Automerge - At any time (no schedule defined).
    This PR was generated by [Mend Renovate](https://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
2025-11-28 docs: contributing & deprecation
    [flexmount.scad]
2025-11-29 deps: update openscad nightly (#99)
    | OpenSCAD-Linux | patch | `2025.11.24.ai29406` -> `2025.11.27.ai29484`
    | OpenSCAD-Windows | patch | `2025.11.24` -> `2025.11.27` |
    that's undesi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
2025-11-29 deps: update camunda/infra-global-github-actions digest to dc24d25 (#101)
    | camunda/infra-global-github-actions | action | digest | `b80b223` ->
    `dc24d25` |
    this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
2025-11-30 deps: update camunda/infra-global-github-actions digest to b0fe528 (#104)
    | camunda/infra-global-github-actions | action | digest | `dc24d25` ->
    `b0fe528` |
    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
2025-12-01 chore(main): release 1.2.0 (#86)
    [1.2.0](https://github.com/kellervater/homeracker/compare/v1.1.0...v1.2.0)
    (2025-11-30)
    * **core:** added more pull-through feet
    ([#85](https://github.com/kellervater/homeracker/issues/85))
    ([d4461c4](https://github.com/kellervater/homeracker/commit/d4461c4f6841d9316901127a4e21240775c7493b))
    * **renovate:** use currentDigest for BOSL2
    ([#92](https://github.com/kellervater/homeracker/issues/92))
    ([99704a5](https://github.com/kellervater/homeracker/commit/99704a500f9154ea270552db3b0274999a8649c7))
    * **renovate:** use full git URL for BOSL2 automerge matching
    ([#96]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
2025-12-06 deps: update belfryscad/bosl2 digest to 44e0c4e (#114)
    | BelfrySCAD/BOSL2 | digest | `266792b` -> `44e0c4e` |
    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
2025-12-06 deps: update camunda/infra-global-github-actions digest to 302d4ca (#115)
    | camunda/infra-global-github-actions | action | digest | `b0fe528` ->
    `302d4ca` |
    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
2025-12-06 deps: update camunda/infra-global-github-actions digest to c779482 (#118)
    | camunda/infra-global-github-actions | action | digest | `302d4ca` ->
    `c779482` |
    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
2025-12-06 deps: update belfryscad/bosl2 digest to b47d5eb (#119)
    | BelfrySCAD/BOSL2 | digest | `44e0c4e` -> `b47d5eb` |
    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
2025-12-07 refactor: uppercase all constants with backward compatibility (#130)
    - Uppercase all constants in `constants.scad` following OpenSCAD naming
    conventions
    - Update all references across `models/core/` directory tree
    - Add deprecated block with lowercase aliases for backward compatibility
    - Improve comment clarity throughout
    ## Backward Compatibility
    Legacy lowercase constants are maintained as aliases to uppercase
    versions:
    ```scad
    // DEPRECATED: Legacy lowercase constants (will be removed in future versions)
    tolerance = TOLERANCE;
    base_unit = BASE_UNIT;
    // ... etc
    ```
    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
    [connector.scad, connectors.scad, lockpin.scad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]
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2025-12-07 deps: update belfryscad/bosl2 digest to b47d5eb (#122)
    | BelfrySCAD/BOSL2 | digest | `266792b` -> `b47d5eb` |
    🚦 **Automerge**: Disabled because a matching PR was automerged
    previously.
    ---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
2025-12-12 fix(core): improve print orientation for bed slingers. (#144)
    I have rotated the parts in my slicer to improve printing on my bed
    slinger.
    Bed slingers mostly move the parts in the Y axis and this IMHO improves
    the stability the part get directly when generated.
    [connector.scad, lockpin.scad, support.scad]
2025-12-13 deps: update belfryscad/bosl2 digest to 961ed6d (#146)
    | BelfrySCAD/BOSL2 | digest | `b47d5eb` -> `961ed6d` |
    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
2025-12-13 deps: update camunda/infra-global-github-actions digest to 1f5a9ae (#147)
    | camunda/infra-global-github-actions | action | digest | `c779482` ->
    `1f5a9ae` |
    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
2025-12-14 deps: update belfryscad/bosl2 digest to 7c6b1da (#151)
    | BelfrySCAD/BOSL2 | digest | `961ed6d` -> `7c6b1da` |
    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
2025-12-14 deps: update camunda/infra-global-github-actions digest to 39cfd35 (#153)
    | camunda/infra-global-github-actions | action | digest | `1f5a9ae` ->
    `39cfd35` |
    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
2025-12-15 chore: release main (#142)
    <details><summary>homeracker: 1.5.0</summary>
    [1.5.0](https://github.com/kellervater/homeracker/compare/homeracker-v1.4.0...homeracker-v1.5.0)
    (2025-12-15)
    * **img:** added HomeRacker Logo svgs
    ([4f264a9](https://github.com/kellervater/homeracker/commit/4f264a9f3896206b0cd6e1778304710921764948))
    * **scadm:** add --version flag
    ([#140](https://github.com/kellervater/homeracker/issues/140))
    ([5a7d98c](https://github.com/kellervater/homeracker/commit/5a7d98cfd33c36f9d6e1df95181c42c5c6195b2f))
    * **core:** improve print orientation for bed slingers.
    ([#144](https://github.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
2025-12-20 deps: update belfryscad/bosl2 digest to 9312b5b (#158)
    | BelfrySCAD/BOSL2 | digest | `7c6b1da` -> `9312b5b` |
    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
2025-12-20 deps: update camunda/infra-global-github-actions digest to 4b7639e (#159)
    | camunda/infra-global-github-actions | action | digest | `39cfd35` ->
    `4b7639e` |
    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
2025-12-27 deps: update camunda/infra-global-github-actions digest to ac7a12d (#164)
    | camunda/infra-global-github-actions | action | digest | `4b7639e` ->
    `ac7a12d` |
    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
2025-12-28 deps: update belfryscad/bosl2 digest to 79d836c (#169)
    | BelfrySCAD/BOSL2 | digest | `9312b5b` -> `79d836c` |
    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
2025-12-31 feat(core): add extended grip type (#173)
    Added grip_type "extended", a reinforced grip is created with an
    extended outer arm to increase contact area and stability.
    <img width="317" height="220" alt="image"
    src="https://github.com/user-attachments/assets/10e5d675-57e0-4b77-a2b7-f231e536591d"
    />
    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
    [connector.scad, lockpin.scad, support.scad]
2026-01-03 deps: update pre-commit hooks (#181)
    [renovatebot/pre-commit-hooks](https://redirect.github.com/renovatebot/pre-commit-hooks)
    | repository | minor | `42.66.11` → `42.70.2` |
    | [rhysd/actionlint](https://redirect.github.com/rhysd/actionlint) |
    repository | patch | `v1.7.9` → `v1.7.10` |
    Note: The `pre-commit` manager in Renovate is not supported by the
    `pre-commit` maintainers or community. Please do not report any problems
    there, instead [create a Discussion in the Renovate
    repository](https://redirect.github.com/renovatebot/renovate/discussions/new)
    if you have any questions.
    ### Rel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
2026-01-03 deps: update camunda/infra-global-github-actions digest to 309fedf (#180)
    | camunda/infra-global-github-actions | action | digest | `ac7a12d` →
    `309fedf` |
    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
2026-01-03 deps: update openscad nightly to v2026 (#182)
    | OpenSCAD-Linux | major | `2025.12.28.ai30176` → `2026.01.02.ai30348` |
    | OpenSCAD-Windows | major | `2025.12.28` → `2026.01.02` |
    - [ ] <!-- rebase-check -->If you want to rebase/retry this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
2026-01-04 deps: update camunda/infra-global-github-actions digest to 084e5ba (#184)
    | camunda/infra-global-github-actions | action | digest | `309fedf` →
    `084e5ba` |
    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
2026-01-04 deps: update dependency openscad-windows to v2026.01.03 (#186)
    | OpenSCAD-Windows | patch | `2026.01.02` → `2026.01.03` |
    This PR was generated by [Mend Ren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
2026-01-05 chore: release main (#176)
    <details><summary>homeracker: 1.6.0</summary>
    [1.6.0](https://github.com/kellervater/homeracker/compare/homeracker-v1.5.2...homeracker-v1.6.0)
    (2026-01-04)
    * **core:** add extended grip type
    ([#173](https://github.com/kellervater/homeracker/issues/173))
    ([7e4b27a](https://github.com/kellervater/homeracker/commit/7e4b27a5ea451d1894c634b91379e17961355494))
    * update camunda/infra-global-github-actions digest to 084e5ba
    ([#184](https://github.com/kellervater/homeracker/issues/184))
    ([0be0d09](https://github.com/kellervater/homeracker/commit/0be0d090b3cb1859dadf3ea482bb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
2026-01-10 deps: update belfryscad/bosl2 digest to ed3afe3 (#188)
    | BelfrySCAD/BOSL2 | digest | `79d836c` → `ed3afe3` |
    This PR was generated by [Mend Renovate](https: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
2026-01-10 deps: update camunda/infra-global-github-actions digest to a708558 (#189)
    | camunda/infra-global-github-actions | action | digest | `084e5ba` →
    `a708558` |
    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
2026-01-11 feat(gridfinity): baseplate & binbase modules (#187)
    Adding a simplistic openscad implementation of the Gridfinity
    specification.
    It uses the specs from
    [grizzie17](https://www.printables.com/@grizzie17) [on
    Printables](https://www.printables.com/model/417152-gridfinity-specification)
    since they are the most precise, especially when it comes to roundings.
    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
    [baseplate.scad, binbase.scad]
2026-01-12 chore: release main (#191)
    <details><summary>homeracker: 1.7.0</summary>
    [1.7.0](https://github.com/kellervater/homeracker/compare/homeracker-v1.6.0...homeracker-v1.7.0)
    (2026-01-12)
    * **gridfinity:** baseplate & binbase modules
    ([#187](https://github.com/kellervater/homeracker/issues/187))
    ([827c041](https://github.com/kellervater/homeracker/commit/827c041989116eb15a5eed1e6ee8c0365037b0f3))
    * update belfryscad/bosl2 digest to ed3afe3
    ([#188](https://github.com/kellervater/homeracker/issues/188))
    ([ab4c7c7](https://github.com/kellervater/homeracker/commit/ab4c7c71ebacf24a18737acfdc579bdc5ae1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
2026-01-18 deps: update dependency openscad-windows to v2026.01.18 (#202)
    | OpenSCAD-Windows | patch | `2026.01.03` → `2026.01.18` |
    This PR was generated by [Mend Renova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
2026-01-18 deps: update belfryscad/bosl2 digest to 7e5dfe5 (#200)
    | BelfrySCAD/BOSL2 | digest | `ed3afe3` → `7e5dfe5` |
    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
2026-01-18 deps: update camunda/infra-global-github-actions digest to 5f8949d (#201)
    | camunda/infra-global-github-actions | action | digest | `a708558` →
    `5f8949d` |
    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
2026-01-18 deps: update pre-commit hooks (#203)
    [adrienverge/yamllint](https://redirect.github.com/adrienverge/yamllint)
    | repository | minor | `v1.37.1` → `v1.38.0` |
    | [psf/black](https://redirect.github.com/psf/black) | repository |
    major | `25.12.0` → `26.1.0` |
    | repository | minor | `42.78.1` → `42.84.0` |
    repositor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
2026-01-24 deps: update belfryscad/bosl2 digest to a9f31f0 (#208)
    | BelfrySCAD/BOSL2 | digest | `7e5dfe5` → `a9f31f0` |
    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
2026-01-24 deps: update camunda/infra-global-github-actions digest to 8a60c6a (#209)
    | camunda/infra-global-github-actions | action | digest | `5f8949d` →
    `8a60c6a` |
    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
2026-01-25 deps: update dependency openscad-windows to v2026.01.19 (#210)
    | OpenSCAD-Windows | patch | `2026.01.18` → `2026.01.19` |
    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
2026-01-25 deps: update dependency openscad-windows to v2026.01.25 (#211)
    | OpenSCAD-Windows | patch | `2026.01.19` → `2026.01.25` |
    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
2026-01-31 deps: update belfryscad/bosl2 digest to ffa493b (#212)
    | BelfrySCAD/BOSL2 | digest | `a9f31f0` → `ffa493b` |
    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
2026-01-31 deps: update camunda/infra-global-github-actions digest to df04776 (#213)
    | camunda/infra-global-github-actions | action | digest | `8a60c6a` →
    `df04776` |
    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
2026-01-31 deps: update dependency openscad-windows to v2026.01.29 (#214)
    | OpenSCAD-Windows | patch | `2026.01.25` → `2026.01.29` |
    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
